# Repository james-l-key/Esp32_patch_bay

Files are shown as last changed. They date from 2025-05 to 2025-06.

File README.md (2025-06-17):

# Esp32_Patch_Bay

## Warning! 

This project is in active hardware and software development. Things may change drastically at a moments notice.

An 8-pedal mono guitar patch bay controlled by an ESP32-S3, allowing dynamic reconfiguration of guitar pedal signal chains via a user interface with an OLED display and push buttons. The project uses analog multiplexers (CD4051B, ADG419BN) and op-amps (TL072) to route audio signals, controlled through shift registers (74HC595) interfaced with the ESP32-S3. The schematic is designed in KiCad 9.0, and the firmware is developed using the ESP-IDF framework.

## Table of Contents
- [Esp32\_Patch\_Bay](#esp32_patch_bay)
  - [Table of Contents](#table-of-contents)
  - [Features](#features)
  - [Hardware](#hardware)
  - [Software](#software)
  - [Installation](#installation)
  - [Usage](#usage)
  - [Project Structure](#project-structure)
  - [Contributing](#contributing)
  - [Issues](#issues)
  - [License](#license)
  - [Acknowledgements](#acknowledgements)

## Features
- **Dynamic Signal Routing**: Reconfigure the signal chain for up to 8 mono guitar pedals using a 9x8 matrix.
- **User Interface**: SSD1306/SH1106 OLED display for configuration feedback, with three push buttons (Program, Pedal 1, Pedal 2) and a Program Mode LED.
- **Low-Latency Audio**: CD4051B and ADG419BN analog multiplexers and TL072 op-amps ensure clean, buffered audio signal routing.
- **ESP32-S3 Control**: High-performance microcontroller for real-time control, programmed via ESP-IDF.
- **Extensible Design**: Easily scalable to support more pedals by adding multiplexers and shift registers.
- **Open Source**: Full schematic (`circuit.kicad_sch`), PCB layout, and firmware provided.

## Hardware
The patch bay is built around an **ESP32-S3** microcontroller and uses analog multiplexers for audio routing. For the complete hardware details, including the **schematic**, **PCB layout**, and **Bill of Materials (BOM)**, please see the dedicated [hardware repository](https://github.com/your-username/esp32_patch_bay_hardware).

## Software
The firmware is written in C using the **ESP-IDF** framework (v5.1 or later) for the ESP32-S3. Key components include:
- **Matrix Control**: `matrix.c` manages the 9x8 signal routing matrix, interfacing with 74HC595 shift registers to set analog switch states.
- **OLED Driver**: Displays the current signal chain and configuration status.
- **Button Handling**: Debounced inputs for Program, Pedal 1, and Pedal 2 buttons to navigate and set configurations.
- **LED Control**: Toggles the Program Mode LED based on user interaction.

### Dependencies
- **ESP-IDF**: Install ESP-IDF v5.1 or later (see [Espressif Documentation](https://docs.espressif.com/projects/esp-idf/en/latest/esp32s3/)).
- **KiCad 9.0**: For viewing/editing the schematic (`circuit.kicad_sch`).
- **I2C Library**: For SSD1306/SH1106 OLED communication (included in ESP-IDF).
- **GPIO Drivers**: Standard ESP-IDF GPIO functions for buttons, LED, and shift registers.

## Installation
### Prerequisites
- **Hardware**:
  - ESP32-S3 development board or custom PCB with the components listed above.
  - 1/4” mono jacks, buttons, LED, resistors (220Ω for LED, 4.7kΩ for pull-ups), and capacitors.
  - ±9V power supply or charge pump circuit.
- **Software**:
  - [ESP-IDF](https://docs.espressif.com/projects/esp-idf/en/latest/esp32s3/get-started/index.html) installed and configured.
  - [KiCad 9.0](https://www.kicad.org/download/) for schematic/PCB design.
  - A C compiler (e.g., `xtensa-esp32s3-elf-gcc`) included with ESP-IDF.
  - Python 3 for ESP-IDF build scripts.

### Steps
1. **Clone the Repository**:
   ```bash
   git clone [https://github.com/phi/Esp32_patch_bay.git](https://github.com/phi/Esp32_patch_bay.git)
   cd Esp32_patch_bay
   
2. **Set Up ESP-IDF**:
        Follow the ESP-IDF Getting Started Guide.
        Ensure the idf.py tool is accessible in your terminal.

3. **Build the Firmware**:
    ```bash
    idf.py set-target esp32s3
    idf.py build
   
5. **Flash the Firmware**:

    Connect the ESP32-S3 to your computer via USB.
    Flash the firmware:
    ```bash

        idf.py -p /dev/ttyUSB0 flash

  Replace /dev/ttyUSB0 with your serial port (e.g., COM3 on Windows).

  6. **Open the Schematic**:
        Launch KiCad 9.0.
        Open circuit.kicad_sch from the repository root.
        Verify connections and assign footprints for PCB layout.

   7. **Assemble the Hardware**:
        Solder components onto a PCB or prototype board based on the schematic.
        Connect 1/4” jacks to guitar, pedals, and amplifier.
        Power the circuit with +3.3V and ±9V supplies.

## Usage

  **Power On**:
        Connect the patch bay to power (+3.3V, ±9V).
        The OLED displays the current signal chain (e.g., Guitar → Pedal 1 → Pedal 2 → Amp).

  **Program Mode**:
        Press the Program button (SW1) to enter Program Mode (LED1 lights up).
        Use Pedal 1 (SW2) and Pedal 2 (SW3) buttons to select the desired signal path.
        Press Program again to save and exit.

  **Signal Routing**:
        The ESP32-S3 updates the 74HC595 shift registers, which set the analog switches to route the audio signal.
        TL072 op-amps buffer the input and output to maintain signal integrity.

  **Monitor**:
        Use the OLED to confirm the signal chain.
        Check the serial output (via idf.py monitor) for debugging.

***Example Signal Chains***

  * Bypass: Guitar → Amp.
  * Single Pedal: Guitar → Pedal 1 → Amp.
  * Dual Pedal: Guitar → Pedal 1 → Pedal 7 → Amp or Guitar → Pedal 2 → Pedal 1 → Amp.

## Project Structure

```md
Esp32_patch_bay/
├── circuit.kicad_sch        # KiCad 9.0 schematic for 3x3 matrix (scalable to 9x8)
├── main/
│   ├── main.c               # Entry point for ESP-IDF firmware
│   ├── matrix.c             # Signal routing matrix control
│   ├── matrix.h             # Header for matrix functions
│   ├── oled.c               # OLED display driver
│   ├── oled.h               # Header for OLED functions
├── CMakeLists.txt           # ESP-IDF project configuration
├── README.md                # This file
├── LICENSE                  # License file (e.g., MIT)
└── docs/
    ├── HARDWARE.md          # Detailed hardware setup
    ├── SOFTWARE.md          # Firmware development guide
    ├── TROUBLESHOOTING.md   # Common issues and solutions
```
## Scaling to 8 Pedals

**The current schematic implements a 9x8 matrix (Guitar In, Amp Out, and 8 pedals In/Out).**

## Contributing

**Contributions are welcome! To contribute**:

  Fork the repository.
  Create a branch (git checkout -b feature/your-feature).
  Commit changes (git commit -m "Add your feature").
  Push to the branch (git push origin feature/your-feature).
  Open a Pull Request.

## Issues

  Report bugs or suggest features via the Issues tab.
  Include reproduction steps and relevant logs (e.g., idf.py monitor output).

## License

This project is licensed under the MIT License. See the [LICENSE](LICENSE) file for details.

## Acknowledgements

  Espressif Systems for the ESP-IDF framework and ESP32-S3.
  KiCad for open-source EDA tools.
  Community: Inspiration from guitar pedalboard designs and open-source hardware projects.

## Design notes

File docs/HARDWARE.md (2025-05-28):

# Hardware Setup

## Bill of Materials (BOM)
| Component | Quantity | Notes |
|---|---|---|
| ESP32-S3 Module | 1 | ESP32-S3-DevKitC recommended |
| SSD1306 OLED | 1 | 128x64, I2C interface |
| CD4051B Multiplexer| Multiple | Analog multiplexer for signal routing |
| ADG419BN Analog Switch| Multiple | SPDT analog switch for signal routing |
| TL072 Op-Amp | 6 | Dual op-amp for buffering |
| 74HC595 Shift Reg. | 4 | 8-bit shift register |
| 1/4” Mono Jack | 18 | For guitar, pedals, and amp |
| Push Button | 10 | Tactile switches |
| LED | 1 | 3mm, any color |
| Resistor (220Ω) | 1 | For LED |
| Resistor (4.7kΩ) | 10 | For button pull-ups |
| Capacitor (100nF)  | 10 | Decoupling for ICs |
| TMA-1215D DC/DC Converter | 1 | Generates isolated ±15V from 12V input [cite: 536] |
| LM7805_TO220 | 1 | Positive 5V linear regulator [cite: 536] |
| LM7905_TO220 | 1 | Negative 5V linear regulator [cite: 536] |
| AMS1117CD-3.3 | 1 | 3.3V linear regulator [cite: 536] |
| Polyfuse | 1 | Resettable fuse for input protection [cite: 536] |
| 1N4007 Diode | 1 | Rectifier diode for input protection [cite: 536] |
| Barrel Jack | 1 | For 12V DC power input [cite: 536] |

## Power Supply
- **Input Power**: The system is designed for an external **12V DC power supply** connected via a barrel jack[cite: 536].
- **Isolated Dual Rails (±15V)**: A TMA-1215D DC/DC converter (U3) takes the 12V input and generates isolated **±15V** rails, which are used by the analog audio circuitry[cite: 536].
- **Regulated +5V**: An LM7805 linear regulator (U2) steps the +15V rail down to a stable **+5V** output, used for various digital components and as input for the 3.3V regulator[cite: 536].
- **Regulated -5V**: An LM7905 linear regulator (U4) converts the -15V rail to a stable **-5V** output[cite: 536].
- **Regulated +3.3V**: An AMS1117-3.3 linear regulator (U1) steps the +5V rail down to a stable **+3.3V** output for the ESP32-S3 and OLED display[cite: 536].
- Ensure proper decoupling capacitors (e.g., 100nF, 10µF) near each IC.

## PCB Design
- Open `circuit.kicad_sch` in KiCad 9.0.
- Assign footprints (e.g., SOIC-16 for CD4051B, DIP-8 for TL072, TO-252-3 for AMS1117-3.3, TO-220-3 for LM7805/LM7905, SIP-7 for TMA-1215D).
- Route PCB with separate analog/digital ground planes for noise reduction.

## Assembly Tips
- Solder ICs first, then passives, then connectors.
- Test power rails before powering on.
- Verify jack connections with a multimeter.

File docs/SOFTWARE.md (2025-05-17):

# Software Development

## ESP-IDF Setup
- Install ESP-IDF v5.1: [Guide](https://docs.espressif.com/projects/esp-idf/en/latest/esp32s3/get-started/index.html).
- Set up the toolchain: `xtensa-esp32s3-elf-gcc`.

## Firmware Structure
- `main.c`: Entry point, initializes matrix and runs main loop.
- `matrix.c/h`: Controls signal routing via 74HC595 and DG408.
- `oled.c/h`: Drives the SSD1306/SH1106 OLED display.

## Adding Features
- **Button Debouncing**: Implement in `main.c` using FreeRTOS timers.
- **OLED Menus**: Extend `oled.c` for interactive configuration.
- **EEPROM Storage**: Save signal chains to ESP32’s flash.

## Debugging
- Use `idf.py monitor` for serial output.
- Enable verbose logging in `matrix.c` for shift register states.

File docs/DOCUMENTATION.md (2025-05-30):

# Documentation Guide for ESP32 Patch Bay

This document explains how to generate and view the documentation for the ESP32 Patch Bay project.

## Prerequisites

To generate documentation, you need to have Doxygen installed:

```bash
# For Ubuntu/Debian
sudo apt-get install doxygen

# For Fedora
sudo dnf install doxygen

# For Arch Linux
sudo pacman -S doxygen

# For macOS
brew install doxygen
```

## Generating Documentation

To generate the documentation, follow these steps:

1. Open a terminal in the project root directory
2. Run the Doxygen command:

```bash
doxygen Doxyfile
```

3. The documentation will be generated in the `docs/doxygen/html` directory

## Viewing Documentation

To view the generated documentation:

1. Open the `docs/doxygen/html/index.html` file in your web browser:

```bash
# Using xdg-open
xdg-open docs/doxygen/html/index.html

# Or using a specific browser
firefox docs/doxygen/html/index.html
```

## Documentation Structure

The generated documentation includes:

- **Main Page**: Overview of the project from the README.md
- **Files**: All source files with their documentation
- **Data Structures**: Structures and typedefs defined in the code
- **Functions**: All documented functions
- **Variables**: Global and static variables

## Updating Documentation

The documentation is automatically generated from:

1. Doxygen comments in the source code
2. Markdown files in the docs directory
3. Project README.md

To update the documentation:
1. Update the relevant Doxygen comments in your source code
2. Modify or add markdown files in the docs directory
3. Regenerate the documentation using the steps above

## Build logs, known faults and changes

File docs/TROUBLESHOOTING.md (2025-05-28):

# Troubleshooting

## Firmware Issues
- **ESP32 Not Booting**:
  - Check USB connection and serial port.
  - Ensure BOOT pin is not held low.
  - Run `idf.py flash monitor` to diagnose.
- **Matrix Not Updating**:
  - Verify GPIO assignments in `matrix.c`.
  - Check 74HC595 and analog switch connections.

## Hardware Issues
- **No Audio**:
  - Test jack connections with a multimeter.
  - Verify TL072 power (±9V) and analog switch select lines.
- **OLED Not Displaying**:
  - Confirm I2C connections (SDA, SCL).
  - Check +3.3V supply to OLED.
- **Buttons Not Responding**:
  - Ensure 4.7kΩ pull-up resistors are connected.
  - Test GPIO inputs with a multimeter.

## Common Errors
- **KiCad Schematic Fails to Load**:
  - Ensure KiCad 9.0 is used (version 20250114).
  - Check for syntax errors in `circuit.kicad_sch`.
- **Shift Register Misbehavior**:
  - Slow down shift clock (add delays in `matrix_update`).
  - Verify VCC/GND connections to 74HC595 and analog switches.

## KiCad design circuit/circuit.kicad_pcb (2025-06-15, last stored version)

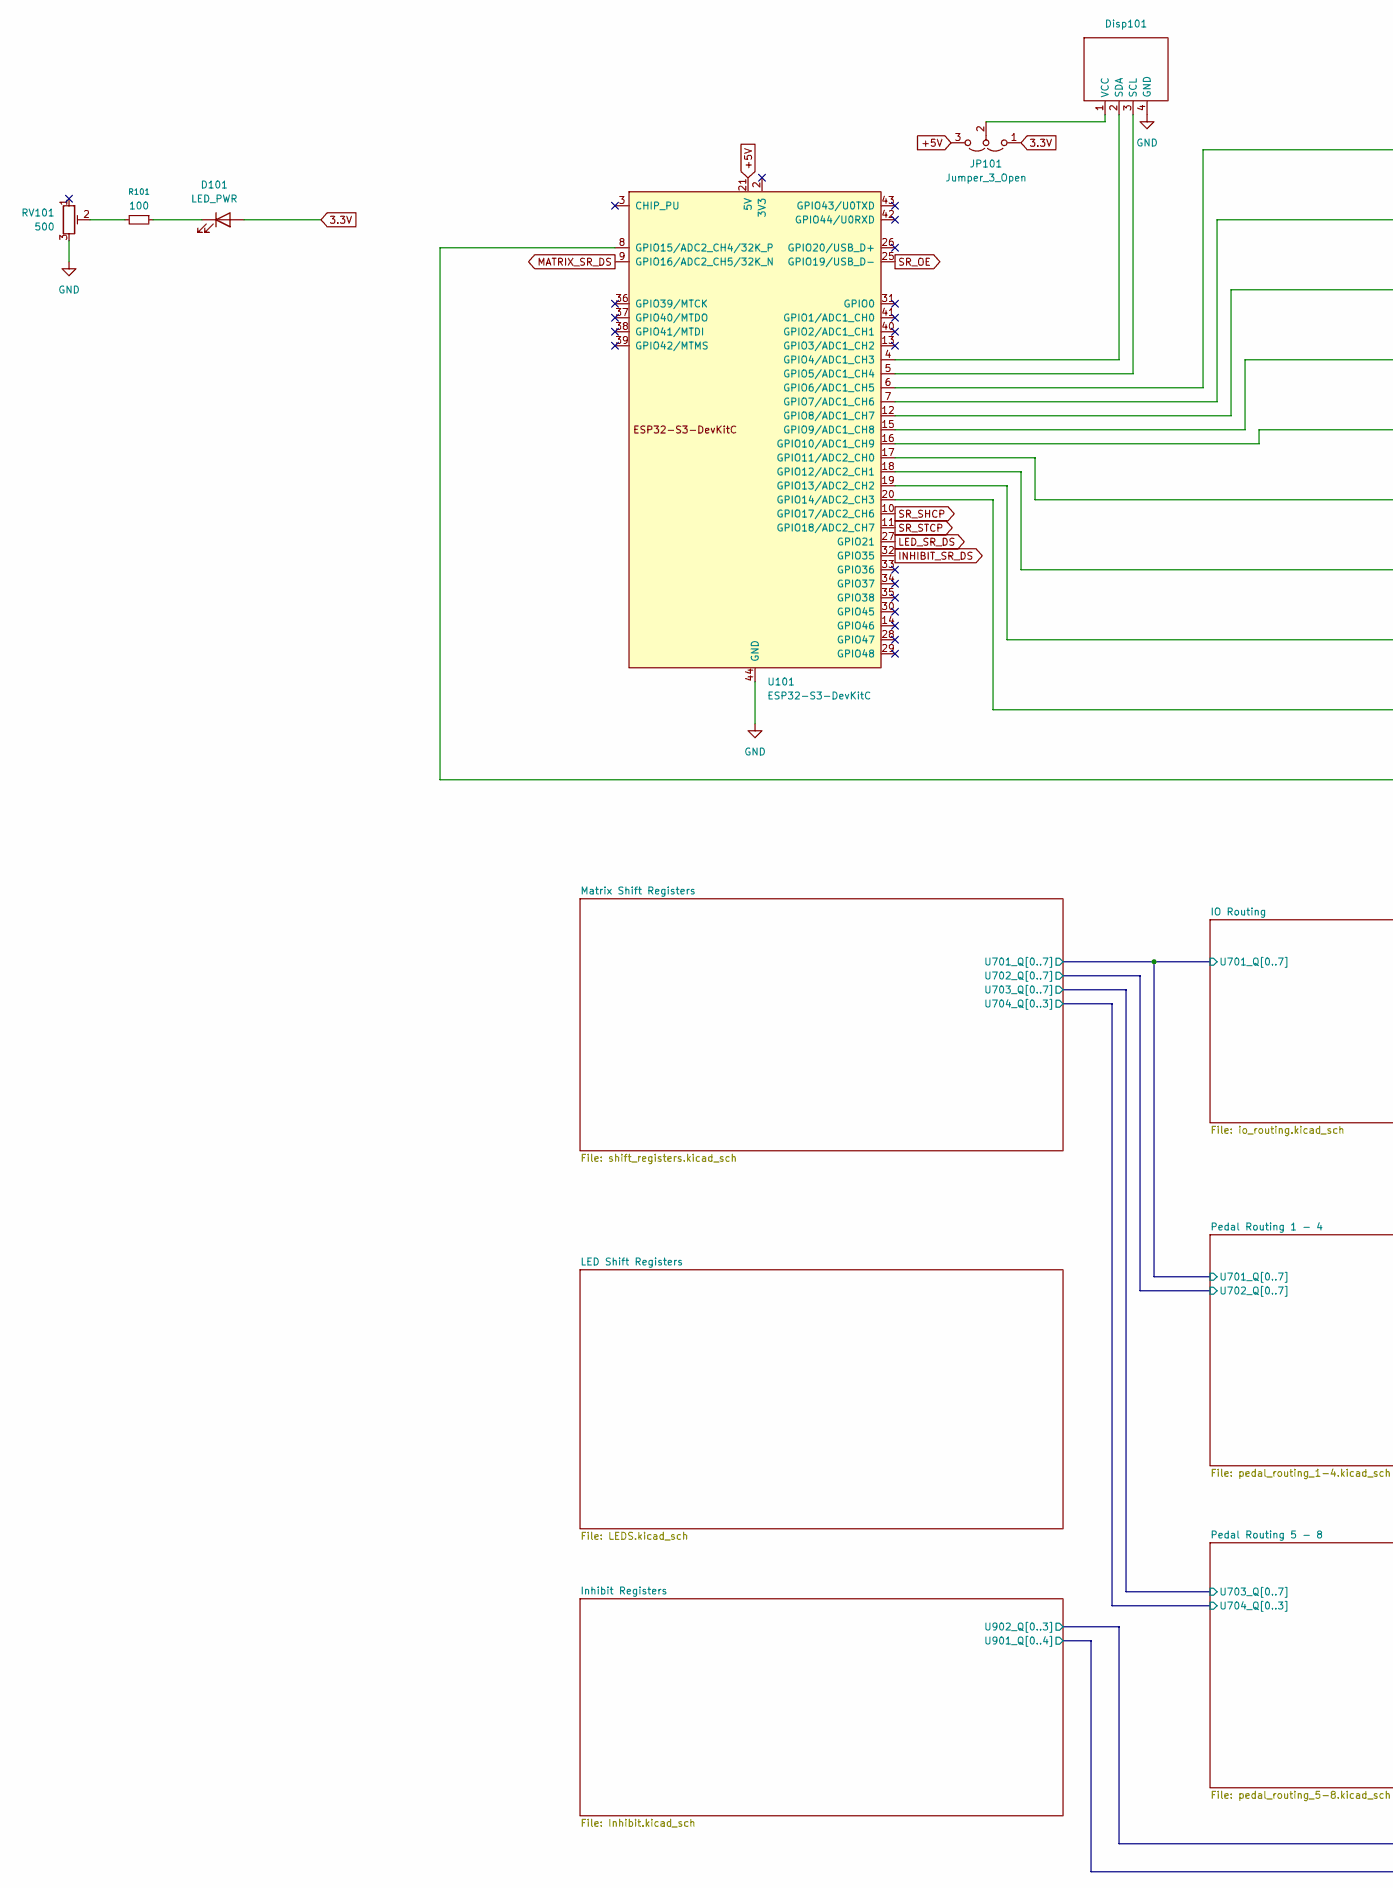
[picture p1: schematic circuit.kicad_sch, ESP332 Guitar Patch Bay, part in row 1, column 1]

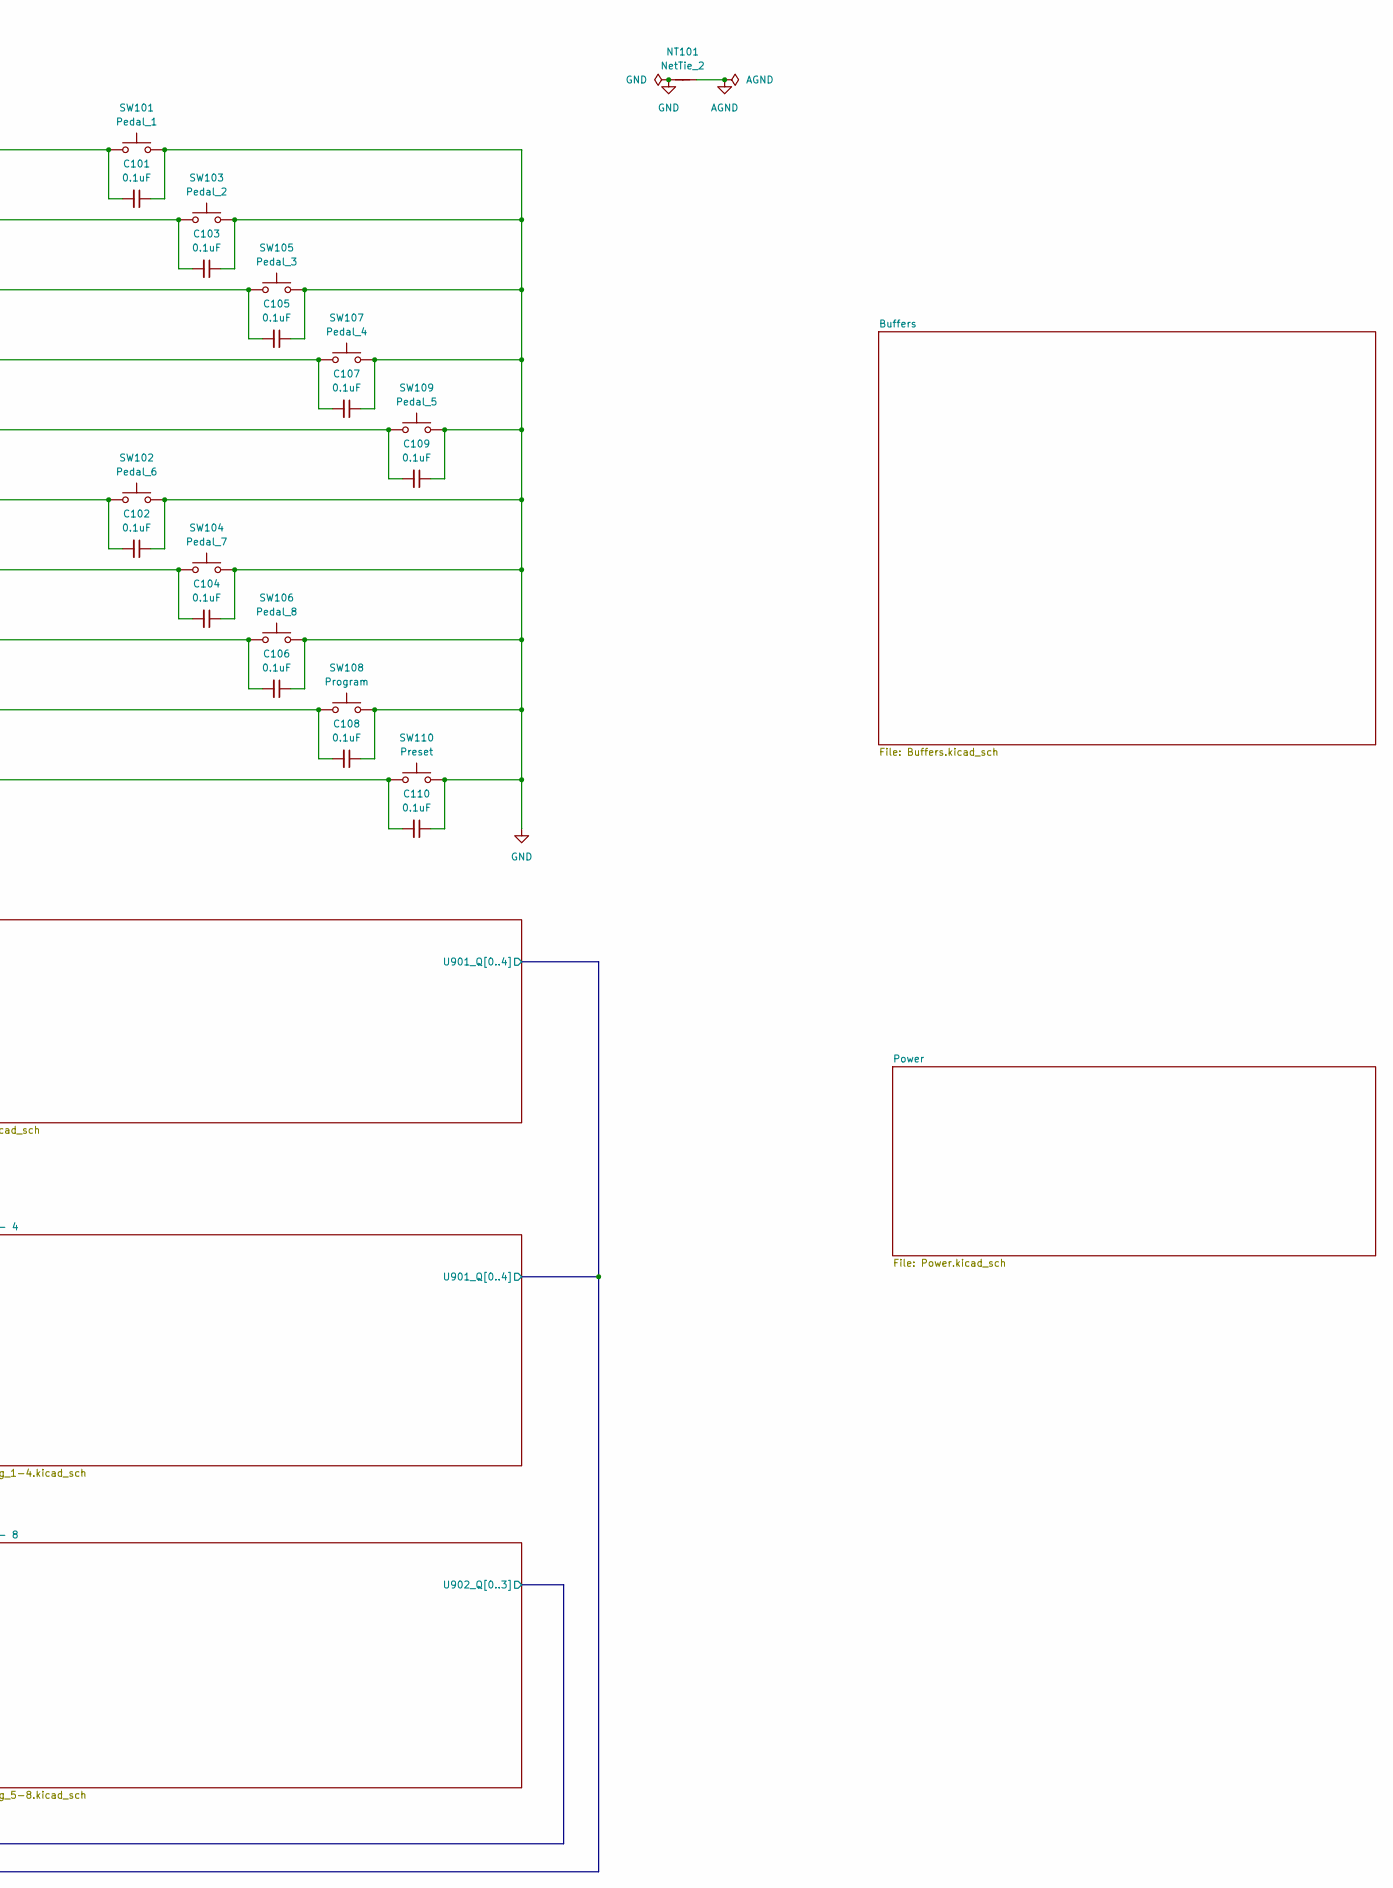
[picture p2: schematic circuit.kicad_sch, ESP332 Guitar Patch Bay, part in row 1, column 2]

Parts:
C101, C102, C103, C104, C105, C106, C107, C108, C109, C110: 0.1uF; C_Disc_D5.0mm_W2.5mm_P2.50mm
D101: LED_PWR; PinHeader_1x02_P2.54mm_Vertical
Disp101: PinHeader_1x04_P2.54mm_Vertical
JP101: Jumper_3_Open; PinSocket_1x03_P2.54mm_Vertical
NT101: NetTie_2; NetTie-2_THT_Pad1.0mm
R101: 100; R_Axial_DIN0207_L6.3mm_D2.5mm_P7.62mm_Horizontal
RV101: 500; Potentiometer_Bourns_3339P_Vertical
SW101: Pedal_1; PinHeader_1x02_P2.54mm_Vertical
SW102: Pedal_6; PinHeader_1x02_P2.54mm_Vertical
SW103: Pedal_2; PinHeader_1x02_P2.54mm_Vertical
SW104: Pedal_7; PinHeader_1x02_P2.54mm_Vertical
SW105: Pedal_3; PinHeader_1x02_P2.54mm_Vertical
SW106: Pedal_8; PinHeader_1x02_P2.54mm_Vertical
SW107: Pedal_4; PinHeader_1x02_P2.54mm_Vertical
SW108: Program; PinHeader_1x02_P2.54mm_Vertical
SW109: Pedal_5; PinHeader_1x02_P2.54mm_Vertical
SW110: Preset; PinHeader_1x02_P2.54mm_Vertical
U101: ESP32-S3-DevKitC

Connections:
3.3V: D101.2 (A), JP101.1 (A); also elsewhere on the board
+5V: JP101.3 (B), U101.21 (5V); also elsewhere on the board
AGND: NT101.2; also elsewhere on the board
GND: C101.1, C102.1, C103.1, C104.1, C105.1, C106.1, C107.1, C108.1, C109.1, C110.1, Disp101.4 (GND), NT101.1, RV101.3, SW101.2, SW102.2, SW103.2, SW104.2, SW105.2, SW106.2, SW107.2, SW108.2, SW109.2, SW110.2, U101.22 (GND), U101.23 (GND), U101.24 (GND), U101.44 (GND); also elsewhere on the board
INHIBIT_SR_DS: U101.32 (GPIO35); also elsewhere on the board
LED_SR_DS: U101.27 (GPIO21); also elsewhere on the board
MATRIX_SR_DS: U101.9 (GPIO16/ADC2_CH5/32K_N); also elsewhere on the board
unnamed: D101.1 (K), R101.1
unnamed: Disp101.3 (SCL), U101.5 (GPIO5/ADC1_CH4)
unnamed: Disp101.2 (SDA), U101.4 (GPIO4/ADC1_CH3)
unnamed: Disp101.1 (VCC), JP101.2 (C)
unnamed: R101.2, RV101.2
unnamed: C101.2, SW101.1, U101.6 (GPIO6/ADC1_CH5)
unnamed: C103.2, SW103.1, U101.7 (GPIO7/ADC1_CH6)
unnamed: C105.2, SW105.1, U101.12 (GPIO8/ADC1_CH7)
unnamed: C107.2, SW107.1, U101.15 (GPIO9/ADC1_CH8)
unnamed: C109.2, SW109.1, U101.16 (GPIO10/ADC1_CH9)
unnamed: C102.2, SW102.1, U101.17 (GPIO11/ADC2_CH0)
unnamed: C104.2, SW104.1, U101.18 (GPIO12/ADC2_CH1)
unnamed: C106.2, SW106.1, U101.19 (GPIO13/ADC2_CH2)
unnamed: C108.2, SW108.1, U101.20 (GPIO14/ADC2_CH3)
unnamed: C110.2, SW110.1, U101.8 (GPIO15/ADC2_CH4/32K_P)
SR_OE: U101.25 (GPIO19/USB_D-); also elsewhere on the board
SR_SHCP: U101.10 (GPIO17/ADC2_CH6); also elsewhere on the board
SR_STCP: U101.11 (GPIO18/ADC2_CH7); also elsewhere on the board

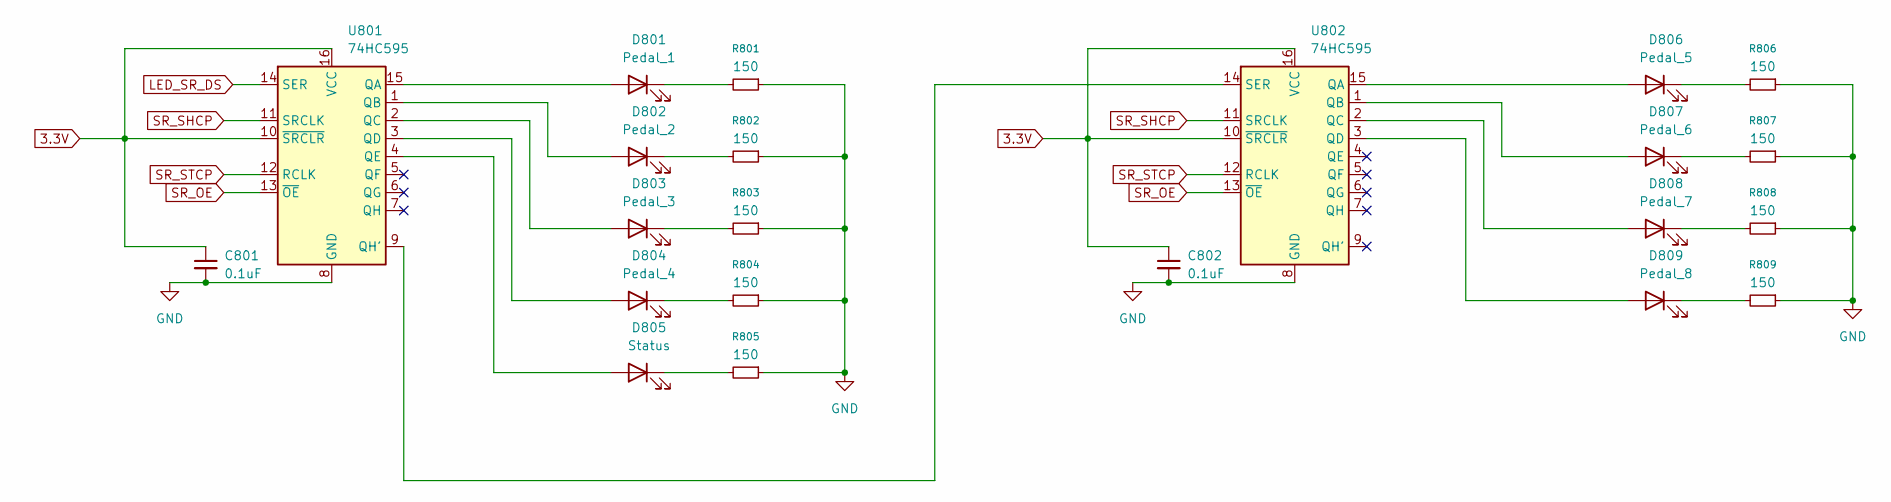
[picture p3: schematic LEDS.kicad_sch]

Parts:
C801, C802: 0.1uF; C_Disc_D5.0mm_W2.5mm_P2.50mm
D801: Pedal_1; PinHeader_1x02_P2.54mm_Vertical
D802: Pedal_2; PinHeader_1x02_P2.54mm_Vertical
D803: Pedal_3; PinHeader_1x02_P2.54mm_Vertical
D804: Pedal_4; PinHeader_1x02_P2.54mm_Vertical
D805: Status; PinHeader_1x02_P2.54mm_Vertical
D806: Pedal_5; PinHeader_1x02_P2.54mm_Vertical
D807: Pedal_6; PinHeader_1x02_P2.54mm_Vertical
D808: Pedal_7; PinHeader_1x02_P2.54mm_Vertical
D809: Pedal_8; PinHeader_1x02_P2.54mm_Vertical
R801, R802, R803, R804, R805, R806, R807, R808, R809: 150; R_Axial_DIN0207_L6.3mm_D2.5mm_P7.62mm_Horizontal
U801, U802: 74HC595; DIP-16_W7.62mm

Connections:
3.3V: C801.1, C802.1, U801.10 (~SRCLR), U801.16 (VCC), U802.10 (~SRCLR), U802.16 (VCC); also elsewhere on the board
GND: C801.2, C802.2, R801.1, R802.1, R803.1, R804.1, R805.1, R806.1, R807.1, R808.1, R809.1, U801.8 (GND), U802.8 (GND); also elsewhere on the board
LED_SR_DS: U801.14 (SER); also elsewhere on the board
unnamed: D801.2 (A), U801.15 (QA)
unnamed: D801.1 (K), R801.2
unnamed: D802.2 (A), U801.1 (QB)
unnamed: D802.1 (K), R802.2
unnamed: D803.2 (A), U801.2 (QC)
unnamed: D803.1 (K), R803.2
unnamed: D804.2 (A), U801.3 (QD)
unnamed: D804.1 (K), R804.2
unnamed: D805.2 (A), U801.4 (QE)
unnamed: D805.1 (K), R805.2
unnamed: D806.2 (A), U802.15 (QA)
unnamed: D806.1 (K), R806.2
unnamed: D807.2 (A), U802.1 (QB)
unnamed: D807.1 (K), R807.2
unnamed: D808.2 (A), U802.2 (QC)
unnamed: D808.1 (K), R808.2
unnamed: D809.2 (A), U802.3 (QD)
unnamed: D809.1 (K), R809.2
unnamed: U801.9 (QH'), U802.14 (SER)
SR_OE: U801.13 (~OE), U802.13 (~OE); also elsewhere on the board
SR_SHCP: U801.11 (SRCLK), U802.11 (SRCLK); also elsewhere on the board
SR_STCP: U801.12 (RCLK), U802.12 (RCLK); also elsewhere on the board

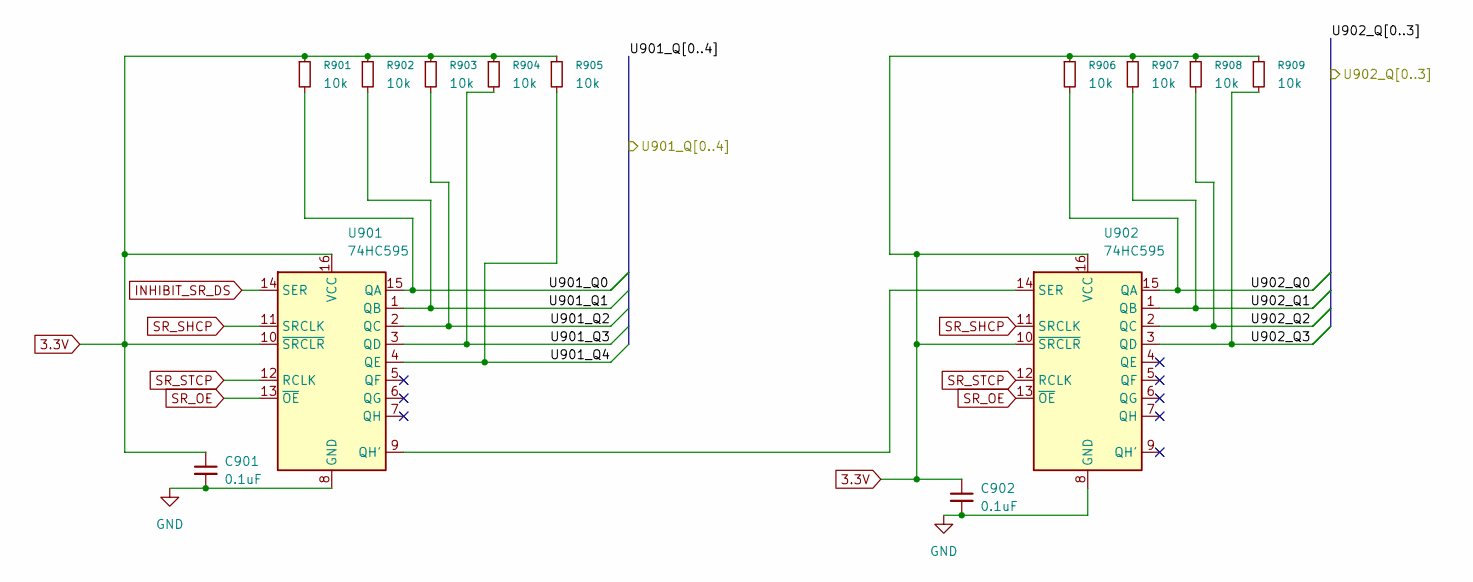
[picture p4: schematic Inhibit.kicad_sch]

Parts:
C901, C902: 0.1uF; C_Disc_D5.0mm_W2.5mm_P2.50mm
R901, R902, R903, R904, R905, R906, R907, R908, R909: 10k; R_Axial_DIN0207_L6.3mm_D2.5mm_P7.62mm_Horizontal
U901, U902: 74HC595; DIP-16_W7.62mm

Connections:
3.3V: C901.1, C902.1, R901.1, R902.1, R903.1, R904.1, R905.1, R906.1, R907.1, R908.1, R909.1, U901.10 (~SRCLR), U901.16 (VCC), U902.10 (~SRCLR), U902.16 (VCC); also elsewhere on the board
/IO Routing/U901_Q0: R901.2, U901.15 (QA); also elsewhere on the board
/IO Routing/U901_Q1: R902.2, U901.1 (QB); also elsewhere on the board
/IO Routing/U901_Q2: R903.2, U901.2 (QC); also elsewhere on the board
/IO Routing/U901_Q3: R904.2, U901.3 (QD); also elsewhere on the board
/IO Routing/U901_Q4: R905.2, U901.4 (QE); also elsewhere on the board
/Inhibit Registers/U902_Q0: R906.2, U902.15 (QA); also elsewhere on the board
/Inhibit Registers/U902_Q1: R907.2, U902.1 (QB); also elsewhere on the board
/Inhibit Registers/U902_Q2: R908.2, U902.2 (QC); also elsewhere on the board
/Inhibit Registers/U902_Q3: R909.2, U902.3 (QD); also elsewhere on the board
GND: C901.2, C902.2, U901.8 (GND), U902.8 (GND); also elsewhere on the board
INHIBIT_SR_DS: U901.14 (SER); also elsewhere on the board
unnamed: U901.9 (QH'), U902.14 (SER)
SR_OE: U901.13 (~OE), U902.13 (~OE); also elsewhere on the board
SR_SHCP: U901.11 (SRCLK), U902.11 (SRCLK); also elsewhere on the board
SR_STCP: U901.12 (RCLK), U902.12 (RCLK); also elsewhere on the board

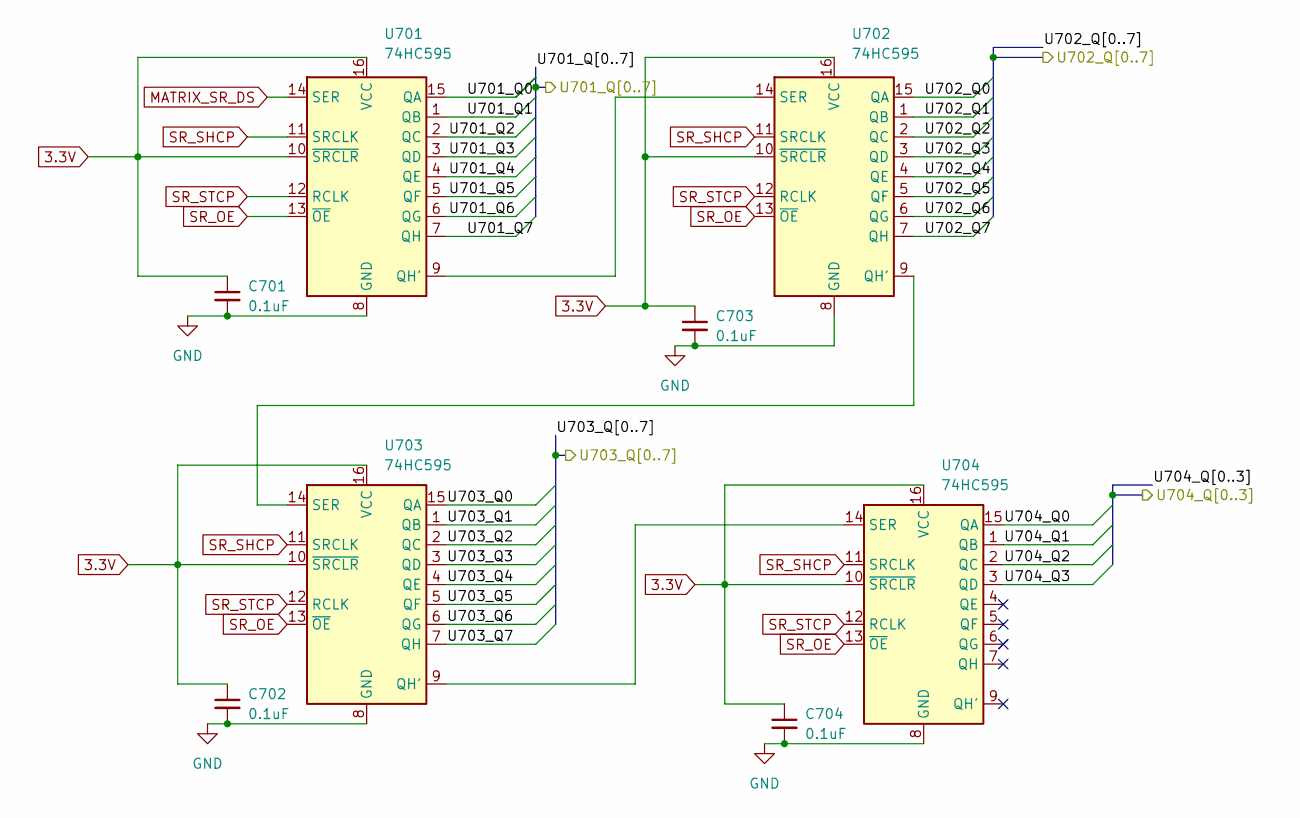
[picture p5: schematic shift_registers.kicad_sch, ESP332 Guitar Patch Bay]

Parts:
C701, C702, C703, C704: 0.1uF; C_Disc_D5.0mm_W2.5mm_P2.50mm
U701, U702, U703, U704: 74HC595; DIP-16_W7.62mm

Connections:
3.3V: C701.1, C702.1, C703.1, C704.1, U701.10 (~SRCLR), U701.16 (VCC), U702.10 (~SRCLR), U702.16 (VCC), U703.10 (~SRCLR), U703.16 (VCC), U704.10 (~SRCLR), U704.16 (VCC); also elsewhere on the board
/IO Routing/U701_Q0: U701.15 (QA); also elsewhere on the board
/IO Routing/U701_Q1: U701.1 (QB); also elsewhere on the board
/IO Routing/U701_Q2: U701.2 (QC); also elsewhere on the board
/IO Routing/U701_Q3: U701.3 (QD); also elsewhere on the board
/IO Routing/U701_Q4: U701.4 (QE); also elsewhere on the board
/IO Routing/U701_Q5: U701.5 (QF); also elsewhere on the board
/IO Routing/U701_Q6: U701.6 (QG); also elsewhere on the board
/IO Routing/U701_Q7: U701.7 (QH); also elsewhere on the board
/Matrix Shift Registers/U702_Q0: U702.15 (QA); also elsewhere on the board
/Matrix Shift Registers/U702_Q1: U702.1 (QB); also elsewhere on the board
/Matrix Shift Registers/U702_Q2: U702.2 (QC); also elsewhere on the board
/Matrix Shift Registers/U702_Q3: U702.3 (QD); also elsewhere on the board
/Matrix Shift Registers/U702_Q4: U702.4 (QE); also elsewhere on the board
/Matrix Shift Registers/U702_Q5: U702.5 (QF); also elsewhere on the board
/Matrix Shift Registers/U702_Q6: U702.6 (QG); also elsewhere on the board
/Matrix Shift Registers/U702_Q7: U702.7 (QH); also elsewhere on the board
/Matrix Shift Registers/U703_Q0: U703.15 (QA); also elsewhere on the board
/Matrix Shift Registers/U703_Q1: U703.1 (QB); also elsewhere on the board
/Matrix Shift Registers/U703_Q2: U703.2 (QC); also elsewhere on the board
/Matrix Shift Registers/U703_Q3: U703.3 (QD); also elsewhere on the board
/Matrix Shift Registers/U703_Q4: U703.4 (QE); also elsewhere on the board
/Matrix Shift Registers/U703_Q5: U703.5 (QF); also elsewhere on the board
/Matrix Shift Registers/U703_Q6: U703.6 (QG); also elsewhere on the board
/Matrix Shift Registers/U703_Q7: U703.7 (QH); also elsewhere on the board
/Matrix Shift Registers/U704_Q0: U704.15 (QA); also elsewhere on the board
/Matrix Shift Registers/U704_Q1: U704.1 (QB); also elsewhere on the board
/Matrix Shift Registers/U704_Q2: U704.2 (QC); also elsewhere on the board
/Matrix Shift Registers/U704_Q3: U704.3 (QD); also elsewhere on the board
GND: C701.2, C702.2, C703.2, C704.2, U701.8 (GND), U702.8 (GND), U703.8 (GND), U704.8 (GND); also elsewhere on the board
MATRIX_SR_DS: U701.14 (SER); also elsewhere on the board
unnamed: U701.9 (QH'), U702.14 (SER)
unnamed: U702.9 (QH'), U703.14 (SER)
unnamed: U703.9 (QH'), U704.14 (SER)
SR_OE: U701.13 (~OE), U702.13 (~OE), U703.13 (~OE), U704.13 (~OE); also elsewhere on the board
SR_SHCP: U701.11 (SRCLK), U702.11 (SRCLK), U703.11 (SRCLK), U704.11 (SRCLK); also elsewhere on the board
SR_STCP: U701.12 (RCLK), U702.12 (RCLK), U703.12 (RCLK), U704.12 (RCLK); also elsewhere on the board

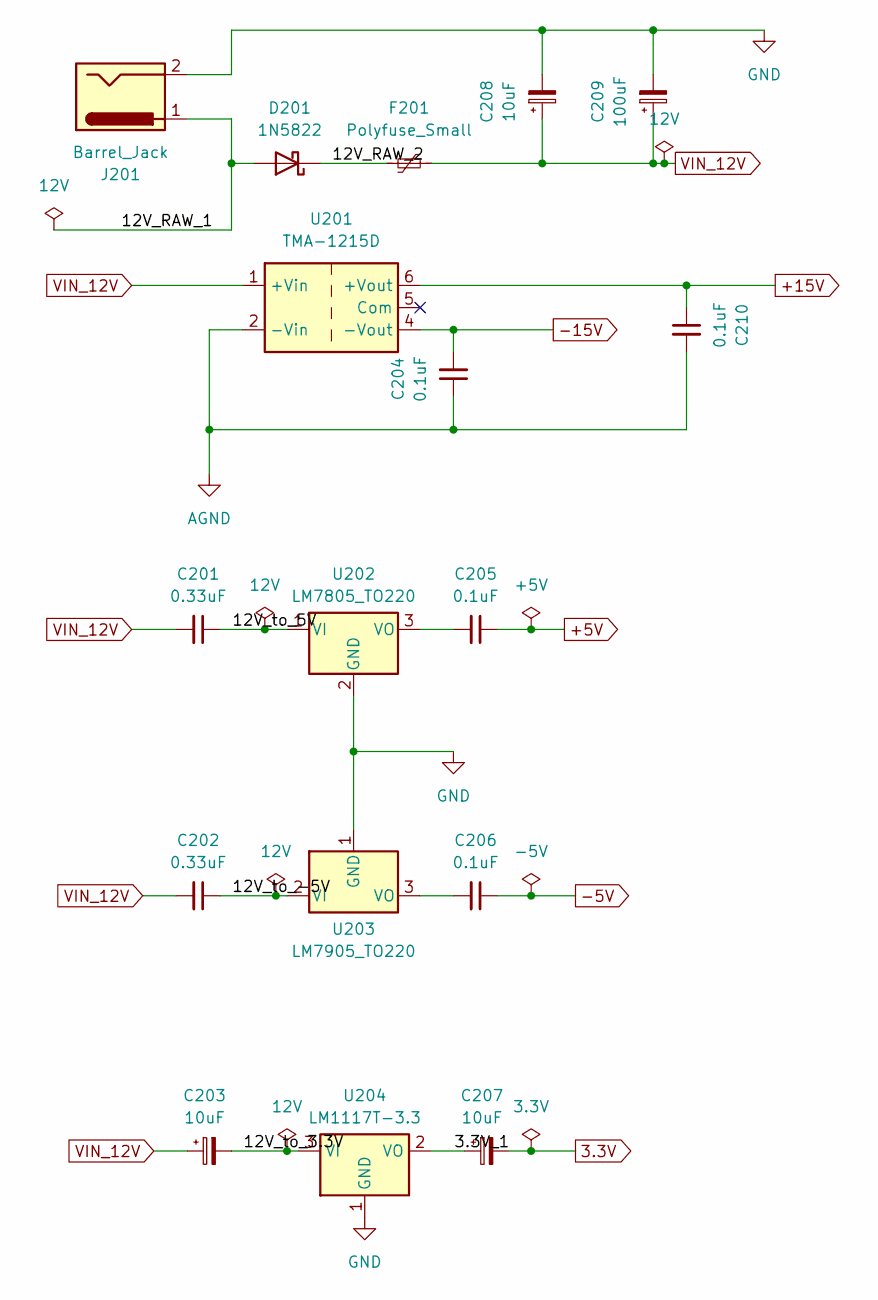
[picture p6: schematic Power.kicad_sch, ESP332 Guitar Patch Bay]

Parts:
C201, C202: 0.33uF; C_Disc_D5.0mm_W2.5mm_P2.50mm
C203, C207, C208: 10uF; CP_Radial_D5.0mm_P2.50mm
C204, C205, C206, C210: 0.1uF; C_Disc_D5.0mm_W2.5mm_P2.50mm
C209: 100uF; CP_Radial_D5.0mm_P2.50mm
D201: 1N5822; D_DO-41_SOD81_P10.16mm_Horizontal
F201: Polyfuse_Small; Fuse_Bourns_MF-RG500
J201: Barrel_Jack; BarrelJack_CUI_PJ-063AH_Horizontal_CircularHoles
U201: TMA-1215D; Converter_DCDC_TRACO_TMA-05xxD_12xxD_Dual_THT
U202: LM7805_TO220; TO-220-3_Vertical
U203: LM7905_TO220; TO-220-3_Vertical
U204: LM1117T-3.3; TO-220-3_Vertical

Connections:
3.3V: C207.2; also elsewhere on the board
+5V: C205.1; also elsewhere on the board
+15V: C210.1, U201.6 (+Vout); also elsewhere on the board
-5V: C206.1; also elsewhere on the board
-15V: C204.2, U201.4 (-Vout); also elsewhere on the board
/Power/3.3V_1: C207.1, U204.2 (VO)
/Power/12V_RAW_1: D201.2 (A), J201.1
/Power/12V_RAW_2: D201.1 (K), F201.2
/Power/12V_to_3.3V: C203.2, U204.3 (VI)
/Power/12V_to_5V: C201.1, U202.1 (VI)
/Power/12V_to_-5V: C202.1, U203.2 (VI)
AGND: C204.1, C210.2, U201.2 (-Vin); also elsewhere on the board
GND: C208.2, C209.2, J201.2, U202.2 (GND), U203.1 (GND), U204.1 (GND); also elsewhere on the board
unnamed: C205.2, U202.3 (VO)
unnamed: C206.2, U203.3 (VO)
VIN_12V: C201.2, C202.2, C203.1, C208.1, C209.1, F201.1, U201.1 (+Vin)

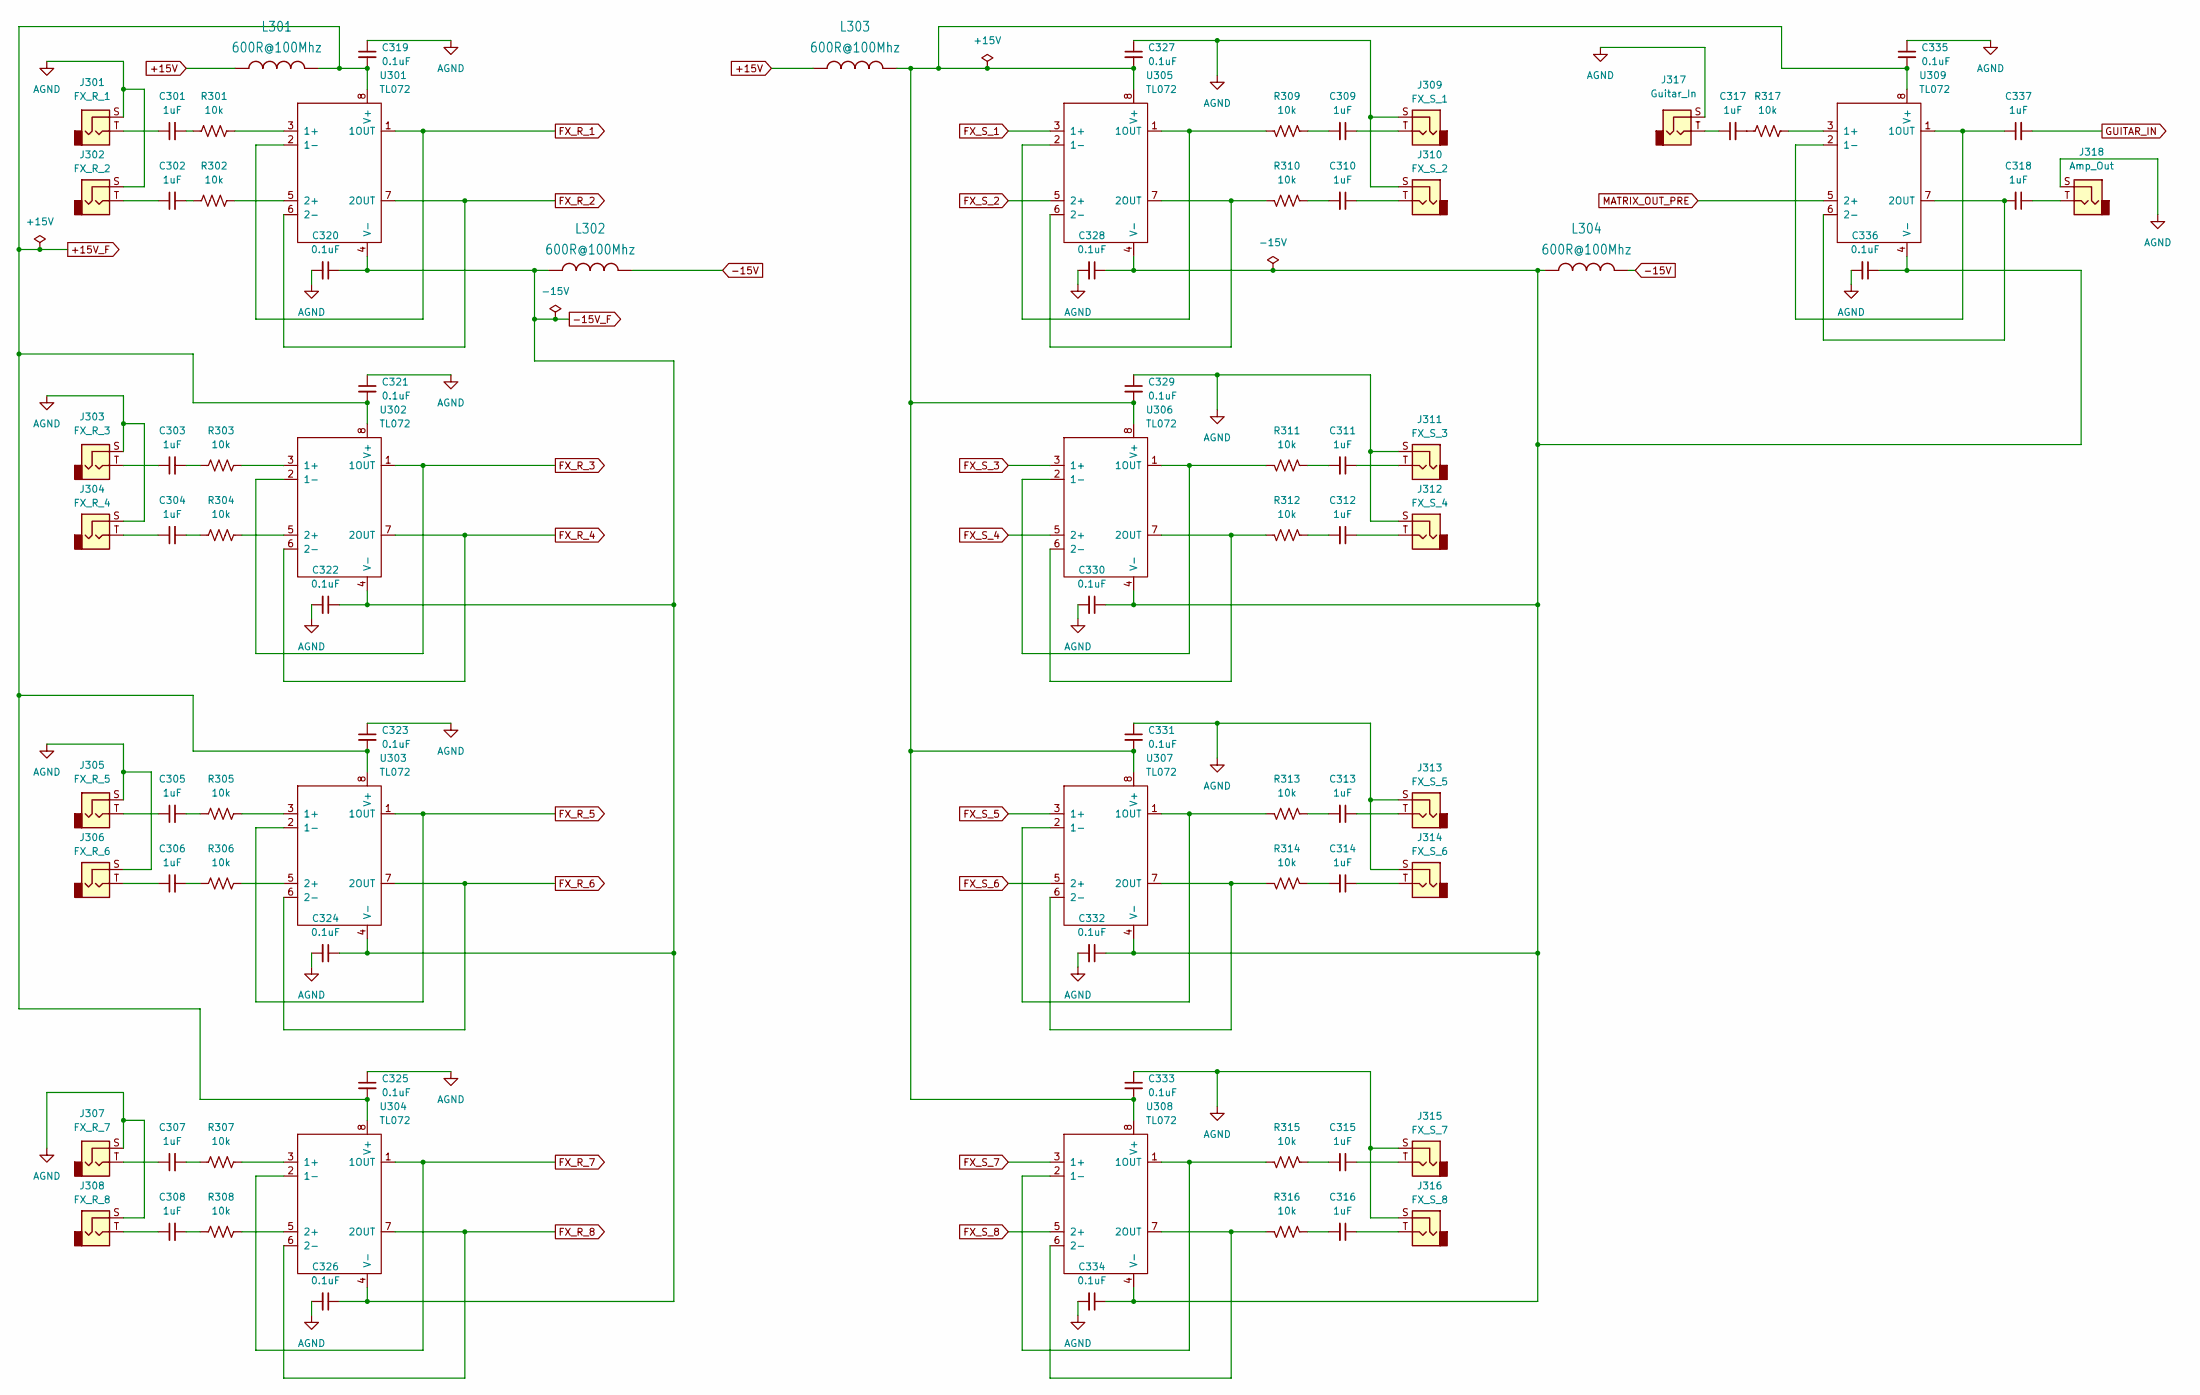
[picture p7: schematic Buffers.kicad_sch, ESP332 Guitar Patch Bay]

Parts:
C301, C302, C303, C304, C305, C306, C307, C308, C309, C310, C311, C312, C313, C314, C315, C316, C317, C318, C337: 1uF; C_Disc_D5.0mm_W2.5mm_P2.50mm
C319, C320, C321, C322, C323, C324, C325, C326, C327, C328, C329, C330, C331, C332, C333, C334, C335, C336: 0.1uF; C_Disc_D5.0mm_W2.5mm_P2.50mm
J301: FX_R_1; Jack
J302: FX_R_2; Jack
J303: FX_R_3; Jack
J304: FX_R_4; Jack
J305: FX_R_5; Jack
J306: FX_R_6; Jack
J307: FX_R_7; Jack
J308: FX_R_8; Jack
J309: FX_S_1; Jack
J310: FX_S_2; Jack
J311: FX_S_3; Jack
J312: FX_S_4; Jack
J313: FX_S_5; Jack
J314: FX_S_6; Jack
J315: FX_S_7; Jack
J316: FX_S_8; Jack
J317: Guitar_In; Jack
J318: Amp_Out; Jack
L301, L302, L303, L304: 600R@100Mhz; WE-UKW_74275010
R301, R302, R303, R304, R305, R306, R307, R308, R309, R310, R311, R312, R313, R314, R315, R316, R317: 10k; R_Axial_DIN0207_L6.3mm_D2.5mm_P7.62mm_Horizontal
U301, U302, U303, U304, U305, U306, U307, U308, U309: TL072; DIP-8_W7.62mm

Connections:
+15V: L301.2, L303.1; also elsewhere on the board
+15V_F: C319.2, C321.2, C323.2, C325.2, L301.1, U301.8 (V+), U302.8 (V+), U303.8 (V+), U304.8 (V+); also elsewhere on the board
-15V: L302.1, L304.2; also elsewhere on the board
-15V_F: C320.1, C322.1, C324.1, C326.1, L302.2, U301.4 (V-), U302.4 (V-), U303.4 (V-), U304.4 (V-); also elsewhere on the board
AGND: C319.1, C320.2, C321.1, C322.2, C323.1, C324.2, C325.1, C326.2, C327.1, C328.2, C329.1, C330.2, C331.1, C332.2, C333.1, C334.2, C335.1, C336.2, J301.S, J302.S, J303.S, J304.S, J305.S, J306.S, J307.S, J308.S, J309.S, J310.S, J311.S, J312.S, J313.S, J314.S, J315.S, J316.S, J317.S, J318.S; also elsewhere on the board
FX_R_1: U301.1 (1OUT), U301.2 (1-); also elsewhere on the board
FX_R_2: U301.6 (2-), U301.7 (2OUT); also elsewhere on the board
FX_R_3: U302.1 (1OUT), U302.2 (1-); also elsewhere on the board
FX_R_4: U302.6 (2-), U302.7 (2OUT); also elsewhere on the board
FX_R_5: U303.1 (1OUT), U303.2 (1-); also elsewhere on the board
FX_R_6: U303.6 (2-), U303.7 (2OUT); also elsewhere on the board
FX_R_7: U304.1 (1OUT), U304.2 (1-); also elsewhere on the board
FX_R_8: U304.6 (2-), U304.7 (2OUT); also elsewhere on the board
FX_S_1: U305.3 (1+); also elsewhere on the board
FX_S_2: U305.5 (2+); also elsewhere on the board
FX_S_3: U306.3 (1+); also elsewhere on the board
FX_S_4: U306.5 (2+); also elsewhere on the board
FX_S_5: U307.3 (1+); also elsewhere on the board
FX_S_6: U307.5 (2+); also elsewhere on the board
FX_S_7: U308.3 (1+); also elsewhere on the board
FX_S_8: U308.5 (2+); also elsewhere on the board
GUITAR_IN: C337.2; also elsewhere on the board
MATRIX_OUT_PRE: U309.5 (2+); also elsewhere on the board
unnamed: C301.1, J301.T
unnamed: C301.2, R301.2
unnamed: C302.1, J302.T
unnamed: C302.2, R302.2
unnamed: C303.1, J303.T
unnamed: C303.2, R303.2
unnamed: C304.1, J304.T
unnamed: C304.2, R304.2
unnamed: C305.1, J305.T
unnamed: C305.2, R305.2
unnamed: C306.1, J306.T
unnamed: C306.2, R306.2
unnamed: C307.1, J307.T
unnamed: C307.2, R307.2
unnamed: C308.1, J308.T
unnamed: C308.2, R308.2
unnamed: C309.1, J309.T
unnamed: C309.2, R309.2
unnamed: C310.1, J310.T
unnamed: C310.2, R310.2
unnamed: C311.1, J311.T
unnamed: C311.2, R311.2
unnamed: C312.1, J312.T
unnamed: C312.2, R312.2
unnamed: C313.1, J313.T
unnamed: C313.2, R313.2
unnamed: C314.1, J314.T
unnamed: C314.2, R314.2
unnamed: C315.1, J315.T
unnamed: C315.2, R315.2
unnamed: C316.1, J316.T
unnamed: C316.2, R316.2
unnamed: C317.1, J317.T
unnamed: C317.2, R317.2
unnamed: C318.1, J318.T
unnamed: R301.1, U301.3 (1+)
unnamed: R302.1, U301.5 (2+)
unnamed: R303.1, U302.3 (1+)
unnamed: R304.1, U302.5 (2+)
unnamed: R305.1, U303.3 (1+)
unnamed: R306.1, U303.5 (2+)
unnamed: R307.1, U304.3 (1+)
unnamed: R308.1, U304.5 (2+)
unnamed: R309.1, U305.1 (1OUT), U305.2 (1-)
unnamed: R310.1, U305.6 (2-), U305.7 (2OUT)
unnamed: C327.2, C329.2, C331.2, C333.2, C335.2, L303.2, U305.8 (V+), U306.8 (V+), U307.8 (V+), U308.8 (V+), U309.8 (V+)
unnamed: C328.1, C330.1, C332.1, C334.1, C336.1, L304.1, U305.4 (V-), U306.4 (V-), U307.4 (V-), U308.4 (V-), U309.4 (V-)
unnamed: R311.1, U306.1 (1OUT), U306.2 (1-)
unnamed: R312.1, U306.6 (2-), U306.7 (2OUT)
unnamed: R313.1, U307.1 (1OUT), U307.2 (1-)
unnamed: R314.1, U307.6 (2-), U307.7 (2OUT)
unnamed: R315.1, U308.1 (1OUT), U308.2 (1-)
unnamed: R316.1, U308.6 (2-), U308.7 (2OUT)
unnamed: R317.1, U309.3 (1+)
unnamed: C337.1, U309.1 (1OUT), U309.2 (1-)
unnamed: C318.2, U309.6 (2-), U309.7 (2OUT)

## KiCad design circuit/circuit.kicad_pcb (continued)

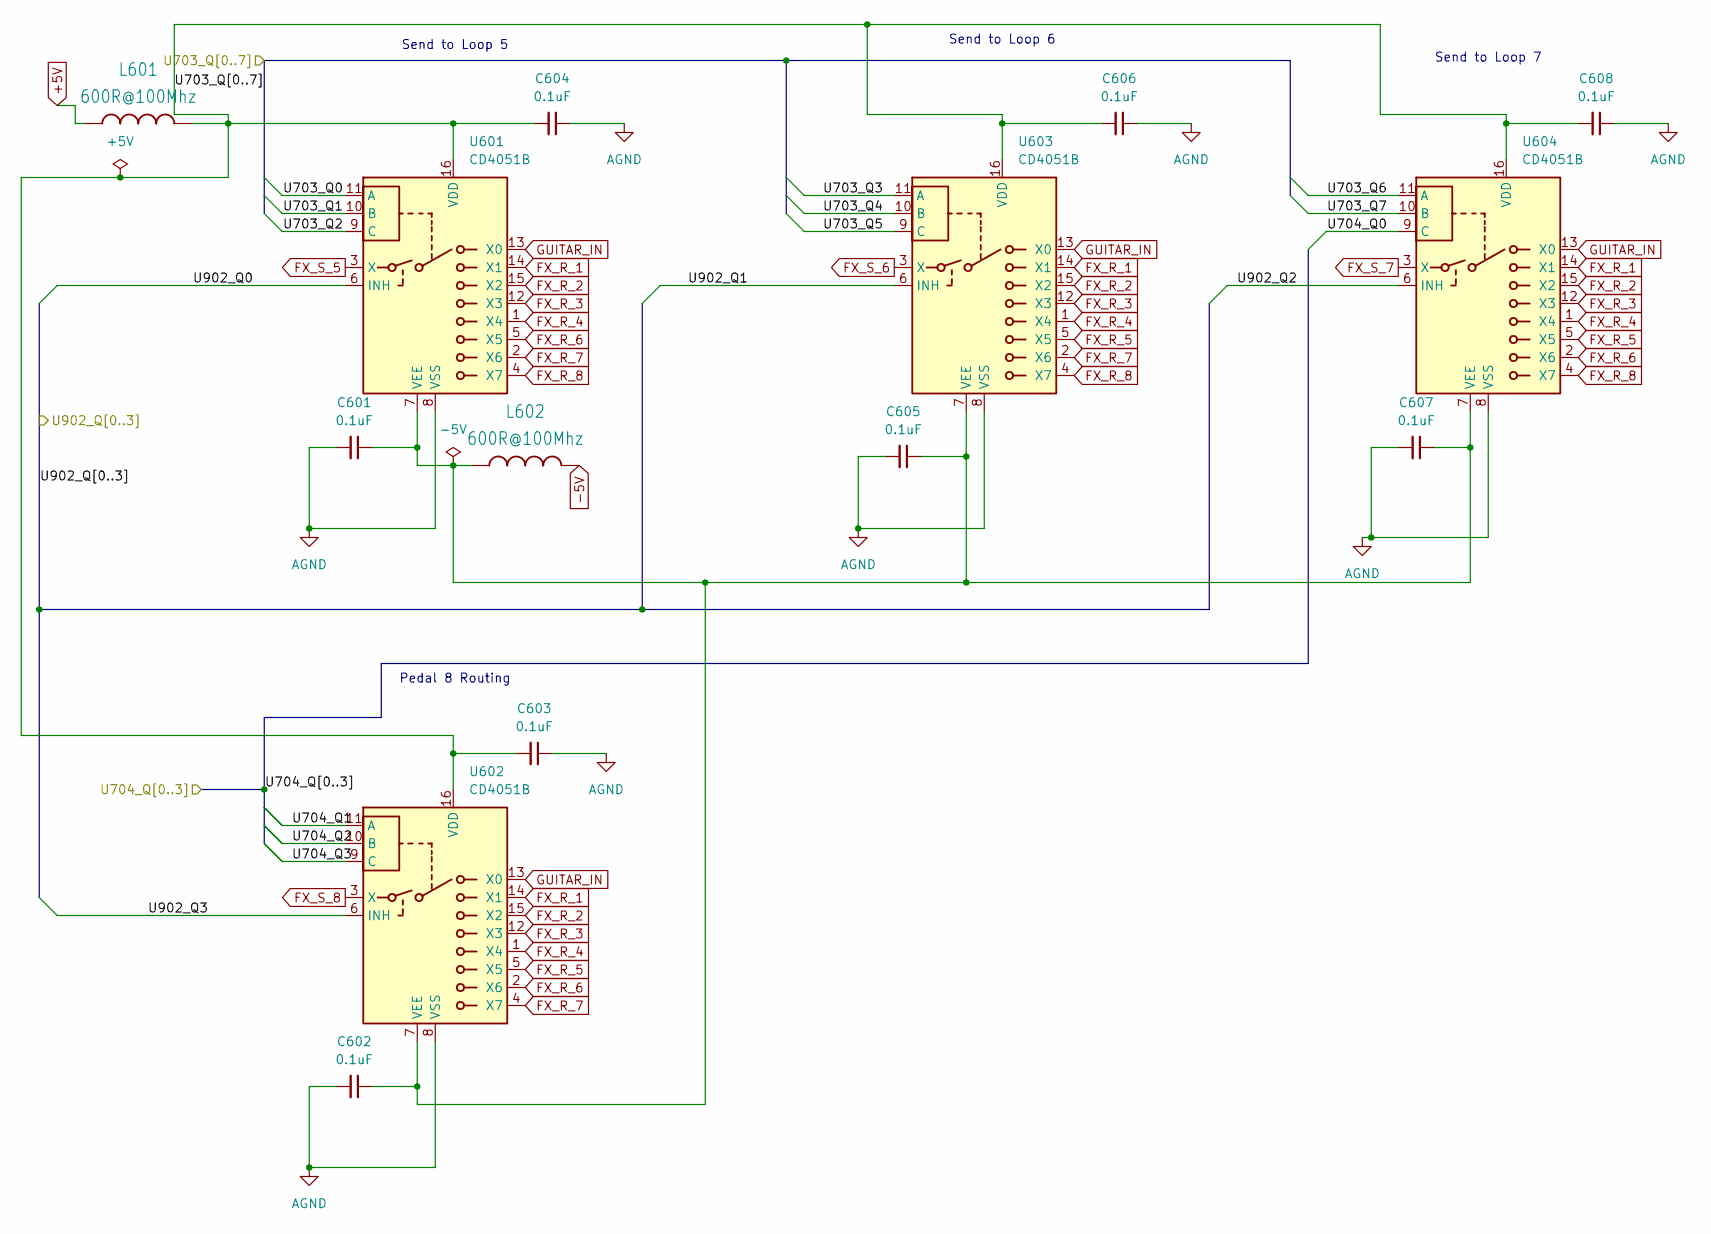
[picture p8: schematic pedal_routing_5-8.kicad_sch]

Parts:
C601, C602, C603, C604, C605, C606, C607, C608: 0.1uF; C_Disc_D5.0mm_W2.5mm_P2.50mm
L601, L602: 600R@100Mhz; WE-UKW_74275010
U601, U602, U603, U604: CD4051B; DIP-16_W7.62mm

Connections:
+5V: L601.1; also elsewhere on the board
-5V: L602.2; also elsewhere on the board
/Inhibit Registers/U902_Q0: U601.6 (INH); also elsewhere on the board
/Inhibit Registers/U902_Q1: U603.6 (INH); also elsewhere on the board
/Inhibit Registers/U902_Q2: U604.6 (INH); also elsewhere on the board
/Inhibit Registers/U902_Q3: U602.6 (INH); also elsewhere on the board
/Matrix Shift Registers/U703_Q0: U601.11 (A); also elsewhere on the board
/Matrix Shift Registers/U703_Q1: U601.10 (B); also elsewhere on the board
/Matrix Shift Registers/U703_Q2: U601.9 (C); also elsewhere on the board
/Matrix Shift Registers/U703_Q3: U603.11 (A); also elsewhere on the board
/Matrix Shift Registers/U703_Q4: U603.10 (B); also elsewhere on the board
/Matrix Shift Registers/U703_Q5: U603.9 (C); also elsewhere on the board
/Matrix Shift Registers/U703_Q6: U604.11 (A); also elsewhere on the board
/Matrix Shift Registers/U703_Q7: U604.10 (B); also elsewhere on the board
/Matrix Shift Registers/U704_Q0: U604.9 (C); also elsewhere on the board
/Matrix Shift Registers/U704_Q1: U602.11 (A); also elsewhere on the board
/Matrix Shift Registers/U704_Q2: U602.10 (B); also elsewhere on the board
/Matrix Shift Registers/U704_Q3: U602.9 (C); also elsewhere on the board
AGND: C601.2, C602.2, C603.1, C604.1, C605.2, C606.1, C607.2, C608.1, U601.8 (VSS), U602.8 (VSS), U603.8 (VSS), U604.8 (VSS); also elsewhere on the board
FX_R_1: U601.14 (X1), U602.14 (X1), U603.14 (X1), U604.14 (X1); also elsewhere on the board
FX_R_2: U601.15 (X2), U602.15 (X2), U603.15 (X2), U604.15 (X2); also elsewhere on the board
FX_R_3: U601.12 (X3), U602.12 (X3), U603.12 (X3), U604.12 (X3); also elsewhere on the board
FX_R_4: U601.1 (X4), U602.1 (X4), U603.1 (X4), U604.1 (X4); also elsewhere on the board
FX_R_5: U602.5 (X5), U603.5 (X5), U604.5 (X5); also elsewhere on the board
FX_R_6: U601.5 (X5), U602.2 (X6), U604.2 (X6); also elsewhere on the board
FX_R_7: U601.2 (X6), U602.4 (X7), U603.2 (X6); also elsewhere on the board
FX_R_8: U601.4 (X7), U603.4 (X7), U604.4 (X7); also elsewhere on the board
FX_S_5: U601.3 (X); also elsewhere on the board
FX_S_6: U603.3 (X); also elsewhere on the board
FX_S_7: U604.3 (X); also elsewhere on the board
FX_S_8: U602.3 (X); also elsewhere on the board
GUITAR_IN: U601.13 (X0), U602.13 (X0), U603.13 (X0), U604.13 (X0); also elsewhere on the board
unnamed: C603.2, C604.2, C606.2, C608.2, L601.2, U601.16 (VDD), U602.16 (VDD), U603.16 (VDD), U604.16 (VDD)
unnamed: C601.1, C602.1, C605.1, C607.1, L602.1, U601.7 (VEE), U602.7 (VEE), U603.7 (VEE), U604.7 (VEE)

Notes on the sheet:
Pedal 8 Routing
Send to Loop 5
Send to Loop 6
Send to Loop 7

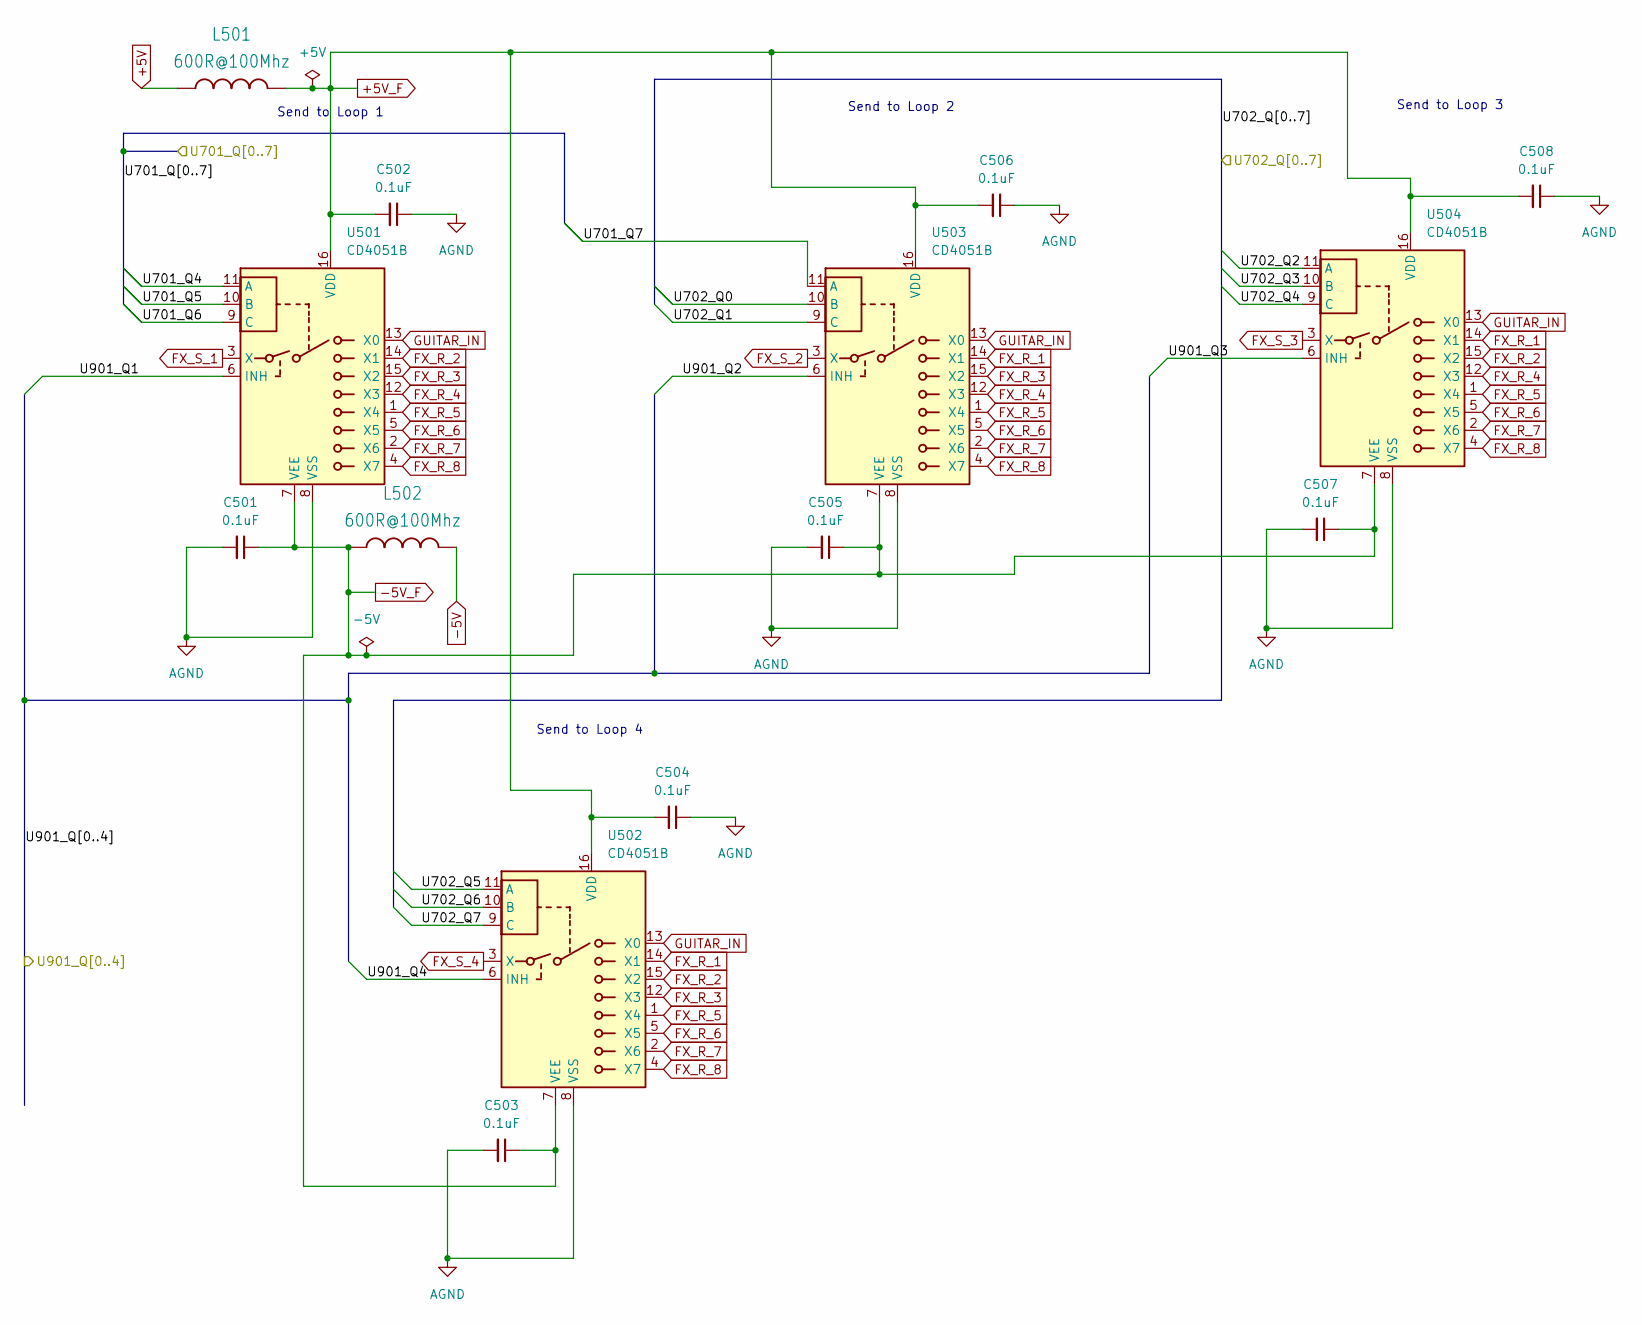
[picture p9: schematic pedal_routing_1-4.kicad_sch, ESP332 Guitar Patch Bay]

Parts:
C501, C502, C503, C504, C505, C506, C507, C508: 0.1uF; C_Disc_D5.0mm_W2.5mm_P2.50mm
L501, L502: 600R@100Mhz; WE-UKW_74275010
U501, U502, U503, U504: CD4051B; DIP-16_W7.62mm

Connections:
+5V: L501.1; also elsewhere on the board
+5V_F: C502.2, C504.2, C506.2, C508.2, L501.2, U501.16 (VDD), U502.16 (VDD), U503.16 (VDD), U504.16 (VDD); also elsewhere on the board
-5V: L502.2; also elsewhere on the board
-5V_F: C501.1, C503.1, C505.1, C507.1, L502.1, U501.7 (VEE), U502.7 (VEE), U503.7 (VEE), U504.7 (VEE); also elsewhere on the board
/IO Routing/U701_Q4: U501.11 (A); also elsewhere on the board
/IO Routing/U701_Q5: U501.10 (B); also elsewhere on the board
/IO Routing/U701_Q6: U501.9 (C); also elsewhere on the board
/IO Routing/U701_Q7: U503.11 (A); also elsewhere on the board
/IO Routing/U901_Q1: U501.6 (INH); also elsewhere on the board
/IO Routing/U901_Q2: U503.6 (INH); also elsewhere on the board
/IO Routing/U901_Q3: U504.6 (INH); also elsewhere on the board
/IO Routing/U901_Q4: U502.6 (INH); also elsewhere on the board
/Matrix Shift Registers/U702_Q0: U503.10 (B); also elsewhere on the board
/Matrix Shift Registers/U702_Q1: U503.9 (C); also elsewhere on the board
/Matrix Shift Registers/U702_Q2: U504.11 (A); also elsewhere on the board
/Matrix Shift Registers/U702_Q3: U504.10 (B); also elsewhere on the board
/Matrix Shift Registers/U702_Q4: U504.9 (C); also elsewhere on the board
/Matrix Shift Registers/U702_Q5: U502.11 (A); also elsewhere on the board
/Matrix Shift Registers/U702_Q6: U502.10 (B); also elsewhere on the board
/Matrix Shift Registers/U702_Q7: U502.9 (C); also elsewhere on the board
AGND: C501.2, C502.1, C503.2, C504.1, C505.2, C506.1, C507.2, C508.1, U501.8 (VSS), U502.8 (VSS), U503.8 (VSS), U504.8 (VSS); also elsewhere on the board
FX_R_1: U502.14 (X1), U503.14 (X1), U504.14 (X1); also elsewhere on the board
FX_R_2: U501.14 (X1), U502.15 (X2), U504.15 (X2); also elsewhere on the board
FX_R_3: U501.15 (X2), U502.12 (X3), U503.15 (X2); also elsewhere on the board
FX_R_4: U501.12 (X3), U503.12 (X3), U504.12 (X3); also elsewhere on the board
FX_R_5: U501.1 (X4), U502.1 (X4), U503.1 (X4), U504.1 (X4); also elsewhere on the board
FX_R_6: U501.5 (X5), U502.5 (X5), U503.5 (X5), U504.5 (X5); also elsewhere on the board
FX_R_7: U501.2 (X6), U502.2 (X6), U503.2 (X6), U504.2 (X6); also elsewhere on the board
FX_R_8: U501.4 (X7), U502.4 (X7), U503.4 (X7), U504.4 (X7); also elsewhere on the board
FX_S_1: U501.3 (X); also elsewhere on the board
FX_S_2: U503.3 (X); also elsewhere on the board
FX_S_3: U504.3 (X); also elsewhere on the board
FX_S_4: U502.3 (X); also elsewhere on the board
GUITAR_IN: U501.13 (X0), U502.13 (X0), U503.13 (X0), U504.13 (X0); also elsewhere on the board

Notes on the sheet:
Send to Loop 2
Send to Loop 3
Send to Loop 4
Send to Loop 1

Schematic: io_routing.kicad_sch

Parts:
C401, C402, C403, C404, C405: 0.1uF; C_Disc_D5.0mm_W2.5mm_P2.50mm
U401: ADG419BN; DIP-8_W7.62mm
U402: CD4051B; DIP-16_W7.62mm

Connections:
+5V_F: C403.1, C405.2, U401.5 (VL), U402.16 (VDD); also elsewhere on the board
+15V_F: C401.1, U401.4 (V+); also elsewhere on the board
-5V_F: C404.1, U402.7 (VEE); also elsewhere on the board
-15V_F: C402.1, U401.7 (V-); also elsewhere on the board
/IO Routing/U701_Q0: U401.6; also elsewhere on the board
/IO Routing/U701_Q1: U402.11 (A); also elsewhere on the board
/IO Routing/U701_Q2: U402.10 (B); also elsewhere on the board
/IO Routing/U701_Q3: U402.9 (C); also elsewhere on the board
/IO Routing/U901_Q0: U402.6 (INH); also elsewhere on the board
AGND: C401.2, C402.2, C403.2, C404.2, C405.1, U401.3 (GND), U402.8 (VSS); also elsewhere on the board
FX_R_1: U402.13 (X0); also elsewhere on the board
FX_R_2: U402.14 (X1); also elsewhere on the board
FX_R_3: U402.15 (X2); also elsewhere on the board
FX_R_4: U402.12 (X3); also elsewhere on the board
FX_R_5: U402.1 (X4); also elsewhere on the board
FX_R_6: U402.5 (X5); also elsewhere on the board
FX_R_7: U402.2 (X6); also elsewhere on the board
FX_R_8: U402.4 (X7); also elsewhere on the board
GUITAR_IN: U401.8; also elsewhere on the board
MATRIX_OUT_PRE: U401.1; also elsewhere on the board
unnamed: U401.2, U402.3 (X)

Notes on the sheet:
Output Mux 1

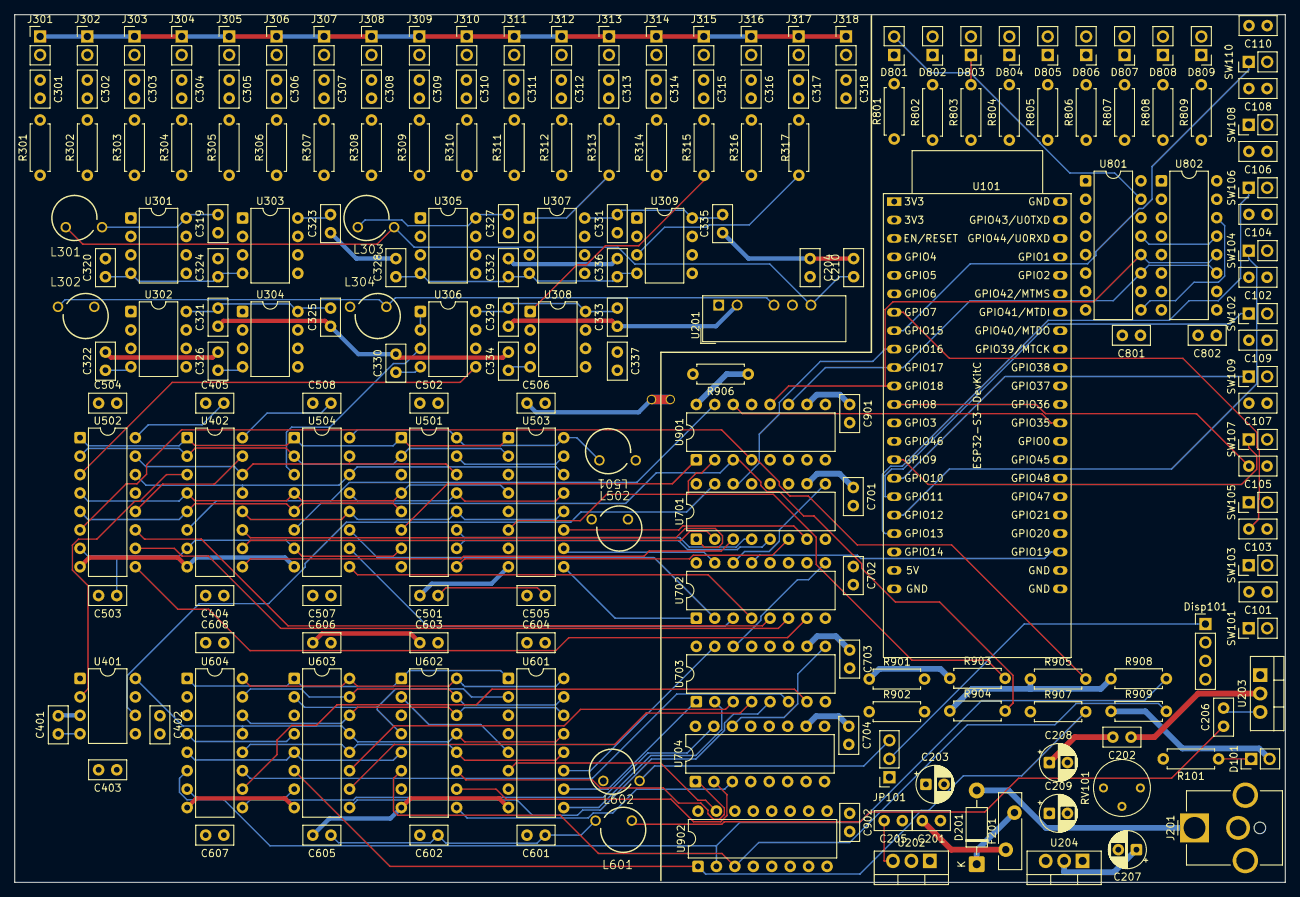
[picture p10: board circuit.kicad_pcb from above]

Board: 4 copper layers, 175.0 x 119.5 mm, 207 parts (0 on the bottom side), 178 nets.

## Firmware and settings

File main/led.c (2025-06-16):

/**
 * @file led.c
 * @brief Implementation of LED control functions for ESP32 patch bay
 *
 * This file implements control of LEDs via 74HC595 shift registers,
 * including individual LED control, multiple LED control with bitmasks,
 * and brightness control using PWM on the output enable pin.
 */
#include <stdio.h>
#include <freertos/FreeRTOS.h>
#include <freertos/task.h>
#include <driver/gpio.h>
#include <esp_log.h>
#include "led.h" // Include our header file

/**
 * @file led.c
 * @brief Implementation of LED control functions for ESP32 patch bay
 *
 * This file implements control of LEDs via 74HC595 shift registers,
 * including individual LED control, multiple LED control with bitmasks,
 * and brightness control using PWM on the output enable pin.
 */

// Define GPIO pins for 74HC595 control (adjust as needed)
#define SER_PIN GPIO_NUM_5   // Serial data input
#define SRCLK_PIN GPIO_NUM_6 // Shift clock
#define RCLK_PIN GPIO_NUM_7  // Latch clock
#define OE_PIN GPIO_NUM_8    // Output enable (active-low)
#define SRCLR_PIN GPIO_NUM_9 // Shift register clear (active-low)

// LED mapping to shift register outputs (0-based index)
#define LED_PEDAL_1 0 // U801 QA
#define LED_PEDAL_3 1 // U801 QB
#define LED_PEDAL_4 2 // U801 QC
#define LED_STATUS 3  // U801 QD
#define LED_PEDAL_5 4 // U802 QA
#define LED_PEDAL_6 5 // U802 QB
#define LED_PEDAL_7 6 // U802 QC
#define LED_PEDAL_8 7 // U802 QD

// PWM parameters for dimming
#define PWM_PERIOD_MS 10                 // 10ms period (100Hz PWM frequency)
    static uint8_t pwm_duty_cycle = 100; // 0-100%, default full brightness
static volatile bool pwm_running = false;
static TaskHandle_t pwm_task_handle = NULL;

static const char *TAG = "LED_CONTROL";

// Current state of LEDs (0 = on, 1 = off for active-low)
static uint8_t led_state = 0xFF; // All LEDs off initially (all bits 1)

// Initialize GPIOs and shift registers
/**
 * Initialize GPIOs and shift registers
 *
 * Configures all necessary GPIO pins and initializes the shift registers
 * to a known state with all LEDs turned off.
 */
void led_init(void)
{
    // Configure GPIO pins
    gpio_config_t io_conf = {
        .pin_bit_mask = (1ULL << SER_PIN) | (1ULL << SRCLK_PIN) | (1ULL << RCLK_PIN) |
                        (1ULL << OE_PIN) | (1ULL << SRCLR_PIN),
        .mode = GPIO_MODE_OUTPUT,
        .pull_up_en = GPIO_PULLUP_DISABLE,
        .pull_down_en = GPIO_PULLDOWN_DISABLE,
        .intr_type = GPIO_INTR_DISABLE};
    gpio_config(&io_conf);

    // Initialize shift register
    gpio_set_level(SRCLR_PIN, 1); // Clear disabled
    gpio_set_level(OE_PIN, 0);    // Outputs enabled
    gpio_set_level(SER_PIN, 0);
    gpio_set_level(SRCLK_PIN, 0);
    gpio_set_level(RCLK_PIN, 0);

    // Clear shift registers
    gpio_set_level(SRCLR_PIN, 0); // Assert clear
    vTaskDelay(1 / portTICK_PERIOD_MS);
    gpio_set_level(SRCLR_PIN, 1); // Release clear

    // Update shift registers with initial state (all off)
    led_update();
}

// Update shift registers with current LED state
/**
 * Update shift registers with current LED state
 *
 * Shifts out the current LED state to the 74HC595 shift registers.
 * This function shifts the bits MSB first for U802, then U801.
 * All updates to LED states should call this function to apply changes.
 */
void led_update(void)
{
    // Shift out 8 bits (MSB first for U802, then U801)
    for (int i = 7; i >= 0; i--)
    {
        gpio_set_level(SER_PIN, (led_state >> i) & 1);
        gpio_set_level(SRCLK_PIN, 1); // Clock pulse
        vTaskDelay(1 / portTICK_PERIOD_MS);
        gpio_set_level(SRCLK_PIN, 0);
    }
    // Latch data to outputs
    gpio_set_level(RCLK_PIN, 1);
    vTaskDelay(1 / portTICK_PERIOD_MS);
    gpio_set_level(RCLK_PIN, 0);
}

// Enable/disable a single LED
/**
 * Enable/disable a single LED
 *
 * Sets the state of a single LED identified by its index.
 * Note that LEDs are active-low in this design (0 = on, 1 = off).
 *
 * @param led_index The LED to control (use LED_* constants from led.h)
 * @param enable true to turn the LED on, false to turn it off
 */
void led_set(uint8_t led_index, bool enable)
{
    if (led_index >= 8)
    {
        ESP_LOGE(TAG, "Invalid LED index: %d", led_index);
        return;
    }
    // Active-low: 0 = on, 1 = off
    if (enable)
    {
        led_state &= ~(1 << led_index); // Clear bit to turn on
    }
    else
    {
        led_state |= (1 << led_index); // Set bit to turn off
    }
    led_update();
}

/**
 * Enable/disable multiple LEDs using a bitmask
 *
 * Sets the state of multiple LEDs at once using a bitmask.
 * This is more efficient than calling led_set() multiple times.
 * Note that LEDs are active-low in this design (0 = on, 1 = off).
 *
 * @param led_mask Bitmask of LEDs to control (set bit for each LED)
 * @param enable true to turn the LEDs on, false to turn them off
 */
void led_set_multiple(uint8_t led_mask, bool enable)
{
    if (enable)
    {
        led_state &= ~led_mask; // Clear bits to turn on
    }
    else
    {
        led_state |= led_mask; // Set bits to turn off
    }
    led_update();
}

// PWM task for dimming all LEDs
/**
 * PWM task for dimming all LEDs
 *
 * FreeRTOS task that implements software PWM by toggling the OE pin
 * of the shift registers at a frequency determined by PWM_PERIOD_MS.
 * The duty cycle controls the ratio of on/off time, affecting brightness.
 *
 * @param pvParameters Task parameters (unused)
 */
void pwm_task(void *pvParameters)
{
    while (pwm_running)
    {
        if (pwm_duty_cycle > 0)
        {
            gpio_set_level(OE_PIN, 0); // Enable outputs
            vTaskDelay((pwm_duty_cycle * PWM_PERIOD_MS / 100) / portTICK_PERIOD_MS);
        }
        if (pwm_duty_cycle < 100)
        {
            gpio_set_level(OE_PIN, 1); // Disable outputs
            vTaskDelay(((100 - pwm_duty_cycle) * PWM_PERIOD_MS / 100) / portTICK_PERIOD_MS);
        }
    }
    gpio_set_level(OE_PIN, 0); // Ensure outputs are enabled when stopping
    vTaskDelete(NULL);
}

/**
 * Set dimming level (0-100%) for all LEDs
 *
 * Controls LED brightness using PWM on the output enable pin.
 * - For 100% brightness, the PWM task is stopped and OE is kept low
 * - For 0% brightness, the PWM task is stopped and OE is kept high
 * - For values between 0-100%, a PWM task is created/managed
 *
 * @param duty_cycle Brightness level (0-100%)
 *                   0 = off, 100 = full brightness
 */
void led_set_brightness(uint8_t duty_cycle)
{
    if (duty_cycle > 100)
    {
        ESP_LOGE(TAG, "Invalid duty cycle: %d", duty_cycle);
        return;
    }
    pwm_duty_cycle = duty_cycle;

    // Start or stop PWM task based on duty cycle
    if (duty_cycle == 100 && pwm_running)
    {
        pwm_running = false; // Stop PWM for full brightness
        vTaskDelete(pwm_task_handle);
        gpio_set_level(OE_PIN, 0); // Enable outputs
    }
    else if (duty_cycle == 0 && pwm_running)
    {
        pwm_running = false; // Stop PWM for fully off
        vTaskDelete(pwm_task_handle);
        gpio_set_level(OE_PIN, 1); // Disable outputs
    }
    else if (!pwm_running && duty_cycle > 0 && duty_cycle < 100)
    {
        pwm_running = true;
        xTaskCreate(pwm_task, "pwm_task", 2048, NULL, 5, &pwm_task_handle);
    }
}

/**
 * Example usage of the LED control functions (commented out)
 *
 * This example demonstrates how to:
 * - Initialize the LED system
 * - Turn individual LEDs on and off
 * - Control multiple LEDs with a bitmask
 * - Adjust LED brightness
 */
/* void app_main(void)
{
    led_init();

    // Example: Turn on Pedal_1 and Status LEDs
    led_set(LED_PEDAL_1, true);
    led_set(LED_STATUS, true);
    vTaskDelay(1000 / portTICK_PERIOD_MS);

    // Example: Turn off Pedal_1
    led_set(LED_PEDAL_1, false);
    vTaskDelay(1000 / portTICK_PERIOD_MS);

    // Example: Turn on Pedal_3, Pedal_4, and Pedal_5 using bitmask
    led_set_multiple((1 << LED_PEDAL_3) | (1 << LED_PEDAL_4) | (1 << LED_PEDAL_5), true);
    vTaskDelay(1000 / portTICK_PERIOD_MS);

    // Example: Dim all LEDs to 50%
    led_set_brightness(50);
    vTaskDelay(2000 / portTICK_PERIOD_MS);

    // Example: Restore full brightness
    led_set_brightness(100);
} */

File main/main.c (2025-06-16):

/**
 * @file main.c
 * @brief Main application for the ESP32 Patch Bay
 *
 * This file contains the main application logic for the ESP32 Patch Bay,
 * including initialization of all subsystems, display setup, and the main
 * application loop.
 */

#include <stdio.h>
#include <freertos/FreeRTOS.h>
#include <freertos/task.h>
#include <driver/gpio.h>
#include <driver/i2c_master.h>
#include <nvs_flash.h>
#include <lvgl.h>
#include <esp_lvgl_port.h>
#include <esp_lcd_panel_io.h>
#include <esp_lcd_panel_ops.h>
#include <esp_log.h>
#include <stdlib.h>
#include <esp_task_wdt.h> // For watchdog functions

#if CONFIG_EXAMPLE_LCD_CONTROLLER_SH1107
#include "esp_lcd_sh1107.h"
#else
#include "esp_lcd_panel_vendor.h"
#endif

#include "sdkconfig.h"
#include "config_check.h"
#include "gui.h"
#include "matrix.h"
#include "buttons.h"
#include "led.h"

//set pwm_duty_cycle to 100% by default
extern uint8_t pwm_duty_cycle = 100; // 0-100%, default full brightness

static const char *TAG = "PatchBayMain";

#define I2C_BUS_PORT 0

// LCD configuration - updated to match working example
#define EXAMPLE_LCD_PIXEL_CLOCK_HZ (400 * 1000)
#define EXAMPLE_PIN_NUM_RST -1
#define EXAMPLE_I2C_HW_ADDR 0x3D // Default OLED I2C address, most displays use 0x3C or 0x3D

// The pixel number in horizontal and vertical
#if CONFIG_EXAMPLE_LCD_CONTROLLER_SSD1306
#define EXAMPLE_LCD_H_RES 128
#define EXAMPLE_LCD_V_RES CONFIG_EXAMPLE_SSD1306_HEIGHT
#elif CONFIG_EXAMPLE_LCD_CONTROLLER_SH1107
#define EXAMPLE_LCD_H_RES 64
#define EXAMPLE_LCD_V_RES 128
#else
// Default to SSD1306 128x64
#define EXAMPLE_LCD_H_RES 128
#define EXAMPLE_LCD_V_RES 64
#endif

// Bit number used to represent command and parameter
#define EXAMPLE_LCD_CMD_BITS 8
#define EXAMPLE_LCD_PARAM_BITS 8

// Forward declarations for display initialization
extern void example_lvgl_demo_ui(lv_disp_t *disp);
static void init_display_and_lvgl(void);

/**
 * @brief Initialize the Non-Volatile Storage (NVS)
 *
 * Sets up the NVS flash storage for saving and loading patch configurations
 * and user presets. Handles erasing and re-initializing if needed.
 */

// Global I2C bus handle - similar to working example
static i2c_master_bus_handle_t i2c_bus = NULL;

void i2c_init(void)
{
    ESP_LOGI(TAG, "Initialize I2C bus");

    // Use modern i2c_master API like in working example
    i2c_master_bus_config_t bus_config = {
        .clk_source = I2C_CLK_SRC_DEFAULT,
        .glitch_ignore_cnt = 7,
        .i2c_port = I2C_BUS_PORT,
        .sda_io_num = CONFIG_I2C_SDA_PIN,
        .scl_io_num = CONFIG_I2C_SCL_PIN,
        .flags.enable_internal_pullup = true,
    };
    ESP_ERROR_CHECK(i2c_new_master_bus(&bus_config, &i2c_bus));

    ESP_LOGI(TAG, "I2C bus initialized successfully");
}

/**
 * @brief Initialize the Non-Volatile Storage (NVS)
 *
 * Sets up the NVS flash storage for saving and loading patch configurations
 * and user presets. Handles erasing and re-initializing if needed.
 */
void nvs_app_init(void)
{
    esp_err_t ret = nvs_flash_init();
    if (ret == ESP_ERR_NVS_NO_FREE_PAGES || ret == ESP_ERR_NVS_NEW_VERSION_FOUND)
    {
        ESP_LOGW(TAG, "NVS: Erasing and re-initializing flash...");
        ESP_ERROR_CHECK(nvs_flash_erase());
        ret = nvs_flash_init();
    }
    ESP_ERROR_CHECK(ret);
    ESP_LOGI(TAG, "NVS Initialized.");
}

/**
 * @brief Initialize display and LVGL - adapted from working example
 */
static void init_display_and_lvgl(void)
{
    ESP_LOGI(TAG, "Install panel IO");
    esp_lcd_panel_io_handle_t io_handle = NULL;
    esp_lcd_panel_io_i2c_config_t io_config = {
        .dev_addr = EXAMPLE_I2C_HW_ADDR, // Use the defined OLED I2C address
        .scl_speed_hz = EXAMPLE_LCD_PIXEL_CLOCK_HZ,
        .control_phase_bytes = 1,               // According to SSD1306 datasheet
        .lcd_cmd_bits = EXAMPLE_LCD_CMD_BITS,   // According to SSD1306 datasheet
        .lcd_param_bits = EXAMPLE_LCD_CMD_BITS, // According to SSD1306 datasheet
#if CONFIG_EXAMPLE_LCD_CONTROLLER_SSD1306
        .dc_bit_offset = 6, // According to SSD1306 datasheet
#elif CONFIG_EXAMPLE_LCD_CONTROLLER_SH1107
        .dc_bit_offset = 0, // According to SH1107 datasheet
        .flags =
            {
                .disable_control_phase = 1,
            }
#endif
    };
    ESP_ERROR_CHECK(esp_lcd_new_panel_io_i2c(i2c_bus, &io_config, &io_handle));

    ESP_LOGI(TAG, "Install LCD panel driver");
    esp_lcd_panel_handle_t panel_handle = NULL;
    esp_lcd_panel_dev_config_t panel_config = {
        .bits_per_pixel = 1,
        .reset_gpio_num = EXAMPLE_PIN_NUM_RST,
    };
#if CONFIG_EXAMPLE_LCD_CONTROLLER_SSD1306
    esp_lcd_panel_ssd1306_config_t ssd1306_config = {
        .height = EXAMPLE_LCD_V_RES,
    };
    panel_config.vendor_config = &ssd1306_config;
    ESP_ERROR_CHECK(esp_lcd_new_panel_ssd1306(io_handle, &panel_config, &panel_handle));
#elif CONFIG_EXAMPLE_LCD_CONTROLLER_SH1107
    ESP_ERROR_CHECK(esp_lcd_new_panel_sh1107(io_handle, &panel_config, &panel_handle));
#else
    // Default to SSD1306 if no specific display is configured
    ESP_LOGI(TAG, "No specific display configured, defaulting to SSD1306");
    esp_lcd_panel_ssd1306_config_t ssd1306_config = {
        .height = EXAMPLE_LCD_V_RES,
    };
    panel_config.vendor_config = &ssd1306_config;
    ESP_ERROR_CHECK(esp_lcd_new_panel_ssd1306(io_handle, &panel_config, &panel_handle));
#endif

    ESP_ERROR_CHECK(esp_lcd_panel_reset(panel_handle));
    ESP_ERROR_CHECK(esp_lcd_panel_init(panel_handle));
    ESP_ERROR_CHECK(esp_lcd_panel_disp_on_off(panel_handle, true));

#if CONFIG_EXAMPLE_LCD_CONTROLLER_SH1107
    ESP_ERROR_CHECK(esp_lcd_panel_invert_color(panel_handle, true));
#endif

    ESP_LOGI(TAG, "Initialize LVGL");
    const lvgl_port_cfg_t lvgl_cfg = ESP_LVGL_PORT_INIT_CONFIG();
    lvgl_port_init(&lvgl_cfg);

    const lvgl_port_display_cfg_t disp_cfg = {
        .io_handle = io_handle,
        .panel_handle = panel_handle,
        .buffer_size = EXAMPLE_LCD_H_RES * EXAMPLE_LCD_V_RES,
        .double_buffer = true,
        .hres = EXAMPLE_LCD_H_RES,
        .vres = EXAMPLE_LCD_V_RES,
        .monochrome = true,
        .rotation = {
            .swap_xy = false,
            .mirror_x = false,
            .mirror_y = false,
        }};
    lv_disp_t *disp = lvgl_port_add_disp(&disp_cfg);

    /* Rotation of the screen */
    lv_disp_set_rotation(disp, LV_DISP_ROTATION_0);

    ESP_LOGI(TAG, "Display LVGL initialization complete");

    // Lock the mutex due to the LVGL APIs are not thread-safe
    if (lvgl_port_lock(0))
    {
        // Initialize GUI instead of demo
        gui_init();
        // Release the mutex
        lvgl_port_unlock();
    }
}
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

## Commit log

2025-05-19 Moved circuit.kikad_sch and made changes to matrix routhing. WIP
    [circuit.kicad_sch]
2025-05-21 Update circuit.kicad_sch
    Swapped DG408 for CD4051B
    [circuit.kicad_sch]
2025-05-22 Update circuit.kicad_sch
    Added Power supplies and Nets.
    [circuit.kicad_sch]
2025-05-23 Circuit nearly complete. Need more decoupling Caps.
    [circuit.kicad_sch]
2025-05-24 Continued prgress on circuit. Split digital and analog gnd.
    [circuit.kicad_sch]
2025-05-25 Editing Circuit for readability.
    [Buffers.kicad_sch, Power.kicad_sch, circuit.kicad_sch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]
2025-05-25 Rebuilt bus and matrix.
    [Buffers.kicad_sch, Power.kicad_sch, circuit.kicad_sch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]
2025-05-26 Hopefully close to finished
    [Buffers.kicad_sch, circuit.kicad_pcb, circuit.kicad_sch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]
2025-05-28 Created pdf and made minor readabilty changes.
    [Buffers.kicad_sch, Power.kicad_sch, circuit.kicad_pcb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]
2025-05-30 Changed default pin assignments and setp sdkconfig.defaults
    [circuit.kicad_pcb]
2025-05-31 Added LEDs and shift registers
    [LEDS.kicad_sch, circuit.kicad_sch, shift_registers.kicad_sch]
2025-06-01 Very tentative PCB layout, Code compiles but needs major functionality testing.
    [LEDS.kicad_sch, Power.kicad_sch, circuit.kicad_pcb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]
2025-06-04 Rebuilt Matrix and added inhibit function.
    Matrix was flawed, It now supports 8 FX loops (pedals) in any order. Or optionally none at all with a buffered bypass, or anywhere in between. The inhibit function will allow the option to press any 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
    [Buffers.kicad_sch, Inhibit.kicad_sch, circuit.kicad_sch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]
2025-06-05 Re-annotation of circuit, new PCB routing, updated PDF
    [Buffers.kicad_sch, Power.kicad_sch, circuit.kicad_pcb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]
2025-06-07 Fine tuning of circuit
    Added jumper to select voltage of display, changed 3.3V regulator from SMD to TO-220 to simplify DIY builds.
    [Buffers.kicad_sch, Power.kicad_sch, circuit.kicad_pcb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]
2025-06-10 Added ferrite beads and tweaked PCB
    [Buffers.kicad_sch, Inhibit.kicad_sch, LEDS.kicad_sch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]
2025-06-15 Circuit tweaks and PCB
    [Buffers.kicad_sch, Inhibit.kicad_sch, LEDS.kicad_sch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]
2025-06-15 Update circuit.pdf
    Update before clean up.
2025-06-15 Labels for headers on PCB
    [Buffers.kicad_sch, LEDS.kicad_sch, Power.kicad_sch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]
2025-06-16 removal of Circuit to create submodule
    [Buffers.kicad_sch, Inhibit.kicad_sch, LEDS.kicad_sch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]
2025-06-16 Added circuit as submodule
2025-06-16 Added led controls
